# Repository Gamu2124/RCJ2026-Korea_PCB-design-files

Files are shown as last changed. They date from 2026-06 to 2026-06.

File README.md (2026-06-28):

# RCJ2026-Korea_PCB-design-files

This repository contains the PCB design files for RoboCup Junior 2026.

### Overview

This repository provides the PCB design files used in the RoboCup Junior 2026 competition.

The files are available for reference, manufacturing, modification, and educational purposes.

### Contents

The repository may include:

* KiCad project files (`.kicad_pro`)
* Schematic files (`.kicad_sch`)
* PCB layout files (`.kicad_pcb`)
* Manufacturing files (Gerber, Drill, etc., if available)
* Custom footprints and symbol libraries (if required)

### Software

These PCB design files were created using **KiCad**.

For the best compatibility, it is recommended to use the same major version of KiCad that was used to create the project.

### Notes

* These files are provided for reference and educational purposes.
* Manufacturing or modifying the boards is done at your own responsibility.
* Some electronic components may require suitable alternatives depending on availability.

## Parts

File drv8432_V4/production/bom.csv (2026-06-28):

Designator | Footprint | Quantity | Value | LCSC Part #
C1, C4, C5, C6, C7 | 0603 | 5 | 0.1u
C2 | C_Elec_8x10.2 | 1 | 220u
C3 | 1206 | 1 | 1u | C1848
D1 | 0603 | 1 | LED
J1, J2 | PinHeader_1x06_P2.54mm_Vertical | 2 | Conn_01x06_Pin
R1 | 0402 | 1 | 47k
R2 | 0603 | 1 | 1
R3 | 0805 | 1 | 25 | C17594
U1 | HSOP-36-1EP_11.0x15.9mm_P0.65mm_SlugUp | 1 | DRV8432

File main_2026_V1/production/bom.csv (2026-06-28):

Designator | Footprint | Quantity | Value | LCSC Part #
BNO_1, J17, J2, NONE_1 | PinSocket_1x04_P2.54mm_Vertical | 4 | Conn_01x04_Socket
C1, C14, C2, C8, C9 | 1206 | 5 | 10
C12, C16, C18, C22, C23, C24, C25, C26, C27, C28, C29, C30, C31, C32, C33, C34, C35, C36, C37, C38, C39, C40, C41, C42, C43, C44 | 0603 | 26 | 0.1 | C1581
C13, C17, C19, C20 | CP_Elec_6.3x5.4 | 4 | 100
C15 | C_Disc_D5.0mm_W2.5mm_P2.50mm | 1 | 0.1
C21 | 0603 | 1 | 0.1 | C1848
C3 | CP_Radial_D10.0mm_P5.00mm | 1 | 1000
C4, C6 | 1206 | 2 | 10uf
C5, C7 | CP_Elec_6.3x5.4 | 2 | 100uf
CAM_1, CAM_2, CAM_3 | SEEED_110990030 | 3 | Conn_01x04_Socket
D1, D2 | D_A-405_P10.16mm_Horizontal | 2 | D_Schottky
D10, D11, D12, D13, D14, D15, D16, D17, D18, D19, D20, D21, D22, D23, D24, D25, D26, D3, D4, D5, D6, D7, D8, D9 | LED_WS2812B_PLCC4_5.0x5.0mm_P3.2mm | 24 | WS2812B
DPDM_1 | PinSocket_1x02_P2.54mm_Vertical | 1 | Conn_01x02_Socket
J1, KICK_1 | JST_XH_B3B-XH-A_1x03_P2.50mm_Vertical | 2 | Conn_01x03_Socket
J10, J13, J16 | PinHeader_2x02_P2.54mm_Vertical | 3 | Conn_02x02_Counter_Clockwise
J11 | JST_XH_B4B-XH-A_1x04_P2.50mm_Vertical | 1 | USS_1
J12 | JST_XH_B4B-XH-A_1x04_P2.50mm_Vertical | 1 | USS_2
J14 | JST_XH_B4B-XH-A_1x04_P2.50mm_Vertical | 1 | USS_3
J15 | JST_XH_B4B-XH-A_1x04_P2.50mm_Vertical | 1 | USS_4
J3 | PinSocket_1x06_P2.54mm_Vertical | 1 | Conn_01x06_Socket
J4, J5 | PinSocket_1x24_P2.54mm_Vertical | 2 | Conn_01x24_Socket
J6 | USB_C_Receptacle_XKB_U262-16XN-4BVC11 | 1 | TYPE-C_LINE
J8 | USB_C_Receptacle_XKB_U262-16XN-4BVC11 | 1 | TYPE-C_BALL
J9 | USB_C_Receptacle_XKB_U262-16XN-4BVC11 | 1 | TYPE-C_main
LED_1, PHOTO_1 | JST_XH_B2B-XH-AM_1x02_P2.50mm_Vertical | 2 | Conn_01x02_Socket
LINE_1, MOTOR_1 | TE_84952-6_1x06-1MP_P1.0mm_Horizontal | 2 | Conn_01x06_Socket
NEOPIX1 | SOT-23 | 1 | BSS138 | C192057
R1, R2 | R_Axial_DIN0207_L6.3mm_D2.5mm_P10.16mm_Horizontal | 2 | 10k
R10, R11, R4, R5, R8, R9 | 0603 | 6 | 5.1k | C26033
R12 | R_Axial_DIN0207_L6.3mm_D2.5mm_P10.16mm_Horizontal | 1 | 3.3k
R13 | R_Axial_DIN0207_L6.3mm_D2.5mm_P10.16mm_Horizontal | 1 | 3.3k | C22978
R14, R17 | 0603 | 2 | 1k | C22978
R15 | R_Axial_DIN0204_L3.6mm_D1.6mm_P5.08mm_Horizontal | 1 | 50
R16 | 0603 | 1 | 100k | C23098
R18, R19 | 1206 | 2 | 10k | C1489
R3 | R_Axial_DIN0207_L6.3mm_D2.5mm_P10.16mm_Horizontal | 1 | 1k
SW1, SW2, SW3, SW4 | Switch_SKRPABE010 | 4 | SW_Push
TACT_1, TACT_2, TACT_3 | SW_PUSH-12mm | 3 | SW_Push
TOGGLE_1 | PinSocket_1x03_P2.54mm_Vertical | 1 | SW_SPDT
U1 | SOT-223 | 1 | LM1117MP-3.3_module
U2 | DPAK172P1054X200-6N | 1 | BD50FD0W_cpu
U3 | DPAK172P1054X200-6N | 1 | BD50FD0W_cam
U4 | SOT-223 | 1 | LM1117MP-3.3
U6 | XIAO-ESP32-S3-DIP | 1 | XIAO-ESP32-S3-DIP_uss
U7 | XIAO-ESP32-S3-DIP | 1 | XIAO-ESP32-S3-DIP_ui

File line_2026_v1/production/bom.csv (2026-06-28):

Designator | Footprint | Quantity | Value | LCSC Part #
C1, C10, C11, C12, C18, C3, C4, C5, C6, C7, C8, C9 | 0402 | 12 | 0.1
C13 | 0402 | 1 | 4.7 | C1872
C14, C15, C2 | 0402 | 3 | 4.7
C16, C17 | 0402 | 2 | 15p | C1548
C19 | CP_Elec_5x5.4 | 1 | 100
C20 | C_Elec_4x5.4 | 1 | 1u | C3348
D1, D10, D11, D12, D13, D14, D15, D16, D17, D18, D19, D2, D20, D21, D22, D23, D24, D25, D26, D27, D28, D29, D3, D30, D31, D32, D35, D36, D37, D38, D4, D41, D42, D43, D44, D47, D48, D49, D5, D50, D6, D7, D8, D9 | 0603 | 44 | NJL
D33 | 0603 | 1 | BLUE
D34 | 0603 | 1 | GREEN
D53, D54, D55, D56, D57, D58, D59, D60, D61, D62, D63, D64 | D_SOD-323 | 12 | SBD
J1 | JST_XH_S2B-XH-A_1x02_P2.50mm_Horizontal | 1 | Conn_01x02_Socket
L1 | Inductor_0806_2016 | 1 | 3.3 | C42411119
LED_1, LED_10, LED_11, LED_12, LED_13, LED_14, LED_15, LED_16, LED_17, LED_18, LED_19, LED_2, LED_20, LED_21, LED_22, LED_23, LED_24, LED_25, LED_26, LED_27, LED_28, LED_29, LED_3, LED_30, LED_31, LED_32, LED_33, LED_34, LED_35, LED_36, LED_39, LED_4, LED_40, LED_41, LED_42, LED_45, LED_46, LED_47, LED_48, LED_5, LED_6, LED_7, LED_8, LED_9 | 0603 | 44 | LED
LINE1 | USB_C_Receptacle_XKB_U262-16XN-4BVC11 | 1 | TYPE-C_LINE
LINE_1 | TE_84952-6_1x06-1MP_P1.0mm_Horizontal | 1 | Conn_01x06_Socket
Q1 | SOT-23 | 1 | AO3400A
R1, R10, R100, R101, R104, R105, R106, R107, R11, R12, R13, R14, R15, R16, R17, R18, R19, R2, R20, R21, R22, R23, R24, R25, R26, R27, R28, R29, R3, R30, R31, R32, R4, R5, R6, R7, R8, R9, R92, R93, R94, R95, R98, R99 | 0603 | 44 | 69.8k | C23098
R110, R111, R112, R113, R114, R115, R116, R117, R118, R119, R120, R121, R33, R34, R35, R36, R37, R38, R39, R40, R41, R42, R43, R44, R45, R46, R47, R48, R49, R50, R51, R52, R53, R54, R55, R56, R57, R58, R59, R60, R61, R62, R63, R64 | 0603 | 44 | 1k | C23098
R128, R129, R131, R132, R134, R135, R71, R72, R73, R74, R75, R76, R77, R78, R79, R80, R81, R82, R83, R84, R85, R86 | 0603 | 22 | 25
R65 | 0603 | 1 | 33 | C177281
R66 | 0402 | 1 | 22 | C174144
R67 | 0402 | 1 | 22
R68 | 0402 | 1 | 1k | C174178
R69 | 0402 | 1 | 15 | C22369173
R70 | 0402 | 1 | 30 | C22356186
R87 | 0805 | 1 | 220
R88 | 0603 | 1 | 10k
R89 | 0603 | 1 | 10k | C23098
R90, R91 | 0603 | 2 | 5.1k | C26033
U1, U10, U11, U12, U13, U14, U15, U16, U17, U18, U19, U2, U20, U21, U22, U3, U4, U5, U6, U7, U8, U9 | SOIC-8_3.9x4.9mm_P1.27mm | 22 | LM393
U25 | RP2350B_QFN-80_EP_10.573x10.573_Pitch0.4mm | 1 | RP2350B-QFN80
U26 | SOIC-8_5.23x5.23mm_P1.27mm | 1 | W25Q128JVS
Y1 | Crystal_SMD_3225-4Pin_3.2x2.5mm | 1 | Crystal_GND24 | C20625731

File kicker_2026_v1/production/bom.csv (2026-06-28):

Designator | Footprint | Quantity | Value | LCSC Part #
D1 | D_SOD-323_HandSoldering | 1 | SBD
D2 | D_SOD-123F | 1 | D
D4 | D_A-405_P10.16mm_Horizontal | 1 | D
J1, SOLE1 | JST_XH_S2B-XH-A_1x02_P2.50mm_Horizontal | 2 | Conn_01x02_Socket
J10, J11, J7, J8 | PinSocket_1x01_P2.54mm_Vertical | 4 | Conn_01x01_Socket
J2, J3 | PinSocket_1x02_P2.54mm_Vertical | 2 | Conn_01x02_Socket
K1 | SMDIP-8_W7.62mm | 1 | AQW212EHA
LED_D1 | 0603 | 1 | LED
MAIN_1 | JST_XH_S3B-XH-A_1x03_P2.50mm_Horizontal | 1 | Conn_01x03_Socket
Q1 | TO-252-2 | 1 | PMOS
Q2 | TO-220-3_Horizontal_TabDown | 1 | NMOS
R1 | 1206 | 1 | 1.6k | C4908
R10 | 1206 | 1 | 68
R11 | 1206 | 1 | 10k
R2 | 1206 | 1 | 1.6k | C102100
R4 | 2512 | 1 | 1k | C31884
R5 | 2512 | 1 | 3.3k | C1469
R6 | 2512 | 1 | 150 | C25471
R9 | 2512 | 1 | 3k | C2934109

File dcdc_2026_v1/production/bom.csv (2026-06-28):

Designator | Footprint | Quantity | Value | LCSC Part #
C1, C7 | Capacitor_0402_1005 | 2 | 0.1
C10, C11, C3, C4, C9 | CP_Elec_5x5.4 | 5 | 22
C12 | CP_Elec_4x5.4 | 1 | 10
C13 | CP_Elec_5x5.7 | 1 | 2.7 | C487141
C2 | CP_Elec_5x5.4 | 1 | 22 | C2887274
C5 | CP_Elec_4x5.4 | 1 | 10 | C2992602
C6 | CP_Elec_5x5.7 | 1 | 2.7
C8 | 0603 | 1 | 0.1
D1 | D_SOD-123F | 1 | D
F1 | Fuseholder_Clip-5x20mm_Keystone_3517_Inline_P23.11x6.76mm_D1.70mm_Horizontal | 1 | Fuse
J1 | PinSocket_1x02_P2.54mm_Vertical | 1 | oled
J2 | AMASS_XT30U-M_1x02_P5.0mm_Vertical | 1 | md
J3 | JST_XH_S3B-XH-A_1x03_P2.50mm_Horizontal | 1 | Conn_01x03_Socket
J4 | JST_XH_S2B-XH-A_1x02_P2.50mm_Horizontal | 1 | md_logic
J5 | JST_XH_S2B-XH-A_1x02_P2.50mm_Horizontal | 1 | line
J6 | JST_XH_S2B-XH-A_1x02_P2.50mm_Horizontal | 1 | kick
L1 | L_Bourns_SRP7028A_7.3x6.6mm | 1 | 3.3
L2 | IND_ETQP5M4R7YFM | 1 | 4.7
LIPO_1 | AMASS_XT30U-M_1x02_P5.0mm_Vertical | 1 | XT30_IN
Q1 | TO-252-2 | 1 | PMOS
R1 | R_Axial_DIN0207_L6.3mm_D2.5mm_P10.16mm_Horizontal | 1 | 10k
R10 | 0805 | 1 | 200k
R11 | 0805 | 1 | 22.1k | C17552
R2 | 0805 | 1 | 69.8k | C17803
R3 | 0402 | 1 | 10.5k | C25850
R4 | 0805 | 1 | 200k | C17539
R5 | 0805 | 1 | 22.1k
R6 | R_Axial_DIN0207_L6.3mm_D2.5mm_P10.16mm_Horizontal | 1 | 10k | C26033
R7 | 0603 | 1 | 150k | C177617
R8 | R_Axial_DIN0207_L6.3mm_D2.5mm_P10.16mm_Horizontal | 1 | 3.3k | C26033
R9 | 0805 | 1 | 22k
RV1 | Potentiometer_Bourns_3314J_Vertical | 1 | 50k
SW | Rocker_SW | 1 | rocker_SW
SW1 | PinSocket_1x02_P2.54mm_Vertical | 1 | SW_SPST
U1 | SO-8EP_DIO | 1 | AP64500SP-3.3v
U2 | SO-8EP_DIO | 1 | AP64500SP-7v

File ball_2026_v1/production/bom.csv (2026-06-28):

Designator | Footprint | Quantity | Value | LCSC Part #
A1, A10, A11, A12, A13, A14, A15, A16, A17, A18, A19, A2, A20, A21, A22, A23, A24, A3, A4, A5, A6, A7, A8, A9 | XDCR_TSSP4038 | 24 | TSSP4038
C1, C16, C4 | 0402 | 3 | 4.7
C10, C13 | 0402 | 2 | 15p | C1548
C11, C12, C14, C15, C2, C5, C6, C7, C8, C9 | 0402 | 10 | 0.1
C17 | CP_Elec_6.3x5.7 | 1 | 150 | C249851
C3 | 0402 | 1 | 4.7 | C1872
D1 | 0603 | 1 | BLUE
D2 | 0603 | 1 | GREEN
J1, J2, J3 | PinHeader_2x02_P2.54mm_Vertical | 3 | Conn_02x02_Counter_Clockwise
L1 | Inductor_0806_2016 | 1 | 3.3 | C42411119
R1 | 0402 | 1 | 15 | C22369173
R2 | 0402 | 1 | 30 | C22356186
R3 | 0402 | 1 | 1k | C174178
R4 | 0603 | 1 | 33 | C177281
R6 | 0402 | 1 | 22 | C174144
R7 | 0402 | 1 | 22
U1 | SOIC-8_5.23x5.23mm_P1.27mm | 1 | W25Q128JVS
U2 | Package_QFN-60-1EP_7x7mm_P0.4mm_EP3.4x3.4mm_hand | 1 | RP2350_60QFN
Y1 | Crystal_SMD_3225-4Pin_3.2x2.5mm | 1 | Crystal_GND24 | C20625731

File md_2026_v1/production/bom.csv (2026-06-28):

Designator | Footprint | Quantity | Value | LCSC Part #
J1 | TE_84952-6_1x06-1MP_P1.0mm_Horizontal | 1 | Conn_01x06_Socket
J1001 | JST_XH_B2B-XH-A_1x02_P2.50mm_Vertical | 1 | Conn_01x02_Socket
J1002, J2 | AMASS_XT30U-M_1x02_P5.0mm_Vertical | 2 | md
J12, J13, J14, J15 | PinSocket_1x06_P2.54mm_Vertical | 4 | Conn_01x06_Socket
J3, J4, J5, J6 | JST_XH_S2B-XH-A_1x02_P2.50mm_Horizontal | 4 | Conn_01x02_Socket
J7 | JST_XH_B2B-XH-A_1x02_P2.50mm_Vertical | 1 | md_logic
R1 | R_Axial_DIN0207_L6.3mm_D2.5mm_P10.16mm_Horizontal | 1 | 10k | C15401

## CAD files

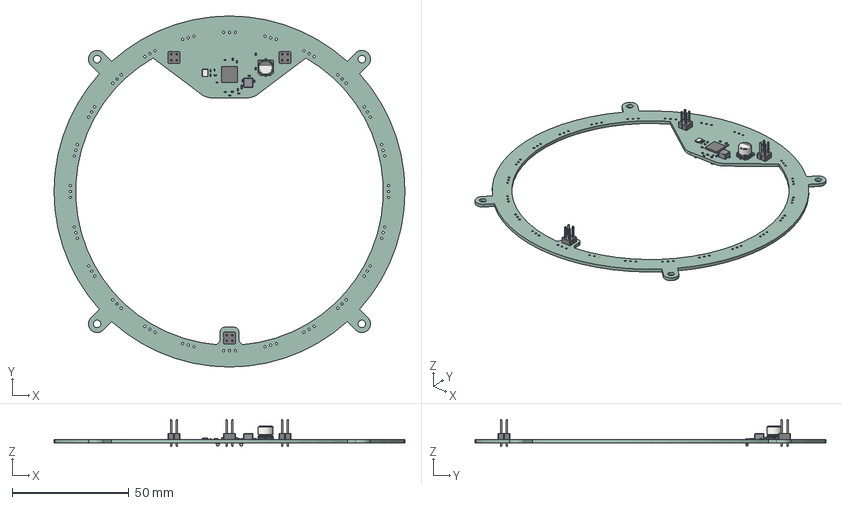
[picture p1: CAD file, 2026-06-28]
ball_2026_v1/ball_2026_v1.step
150.0 x 150.0 x 11.5 mm
C_0402_1005Metric x 16
R_0603_1608Metric
Crystal_SMD_3225-4Pin_3.2x2.5mm
R_0402_1005Metric x 5
QFN-56-1EP_7x7mm_P0.4mm_EP5.6x5.6mm
PinHeader_2x02_P2.54mm_Vertical x 3
L_Abracon_ASPI-0425
CP_Elec_6.3x5.7
LED_0603_1608Metric x 2
ball_2026_v1_PCB

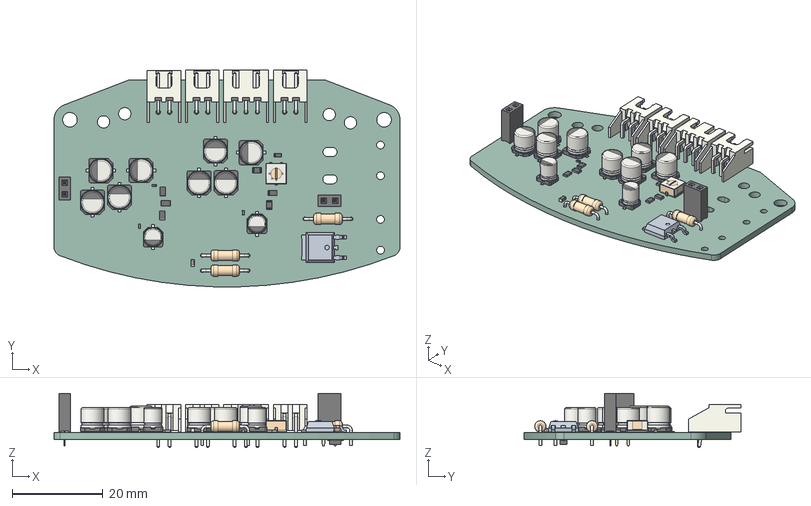
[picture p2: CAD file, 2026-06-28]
dcdc_2026_v1/dcdc_2026_v1.step
76.1 x 47.6 x 11.9 mm
CP_Elec_5x5.4 x 6
C_0402_1005Metric x 2
CP_Elec_4x5.4 x 2
R_0805_2012Metric x 6
PinSocket_1x02_P2.54mm_Vertical x 2
JST_XH_S2B-XH-A_1x02_P2.50mm_Horizontal x 3
R_Axial_DIN0207_L6.3mm_D2.5mm_P10.16mm_Horizontal x 3
Potentiometer_Bourns_3314J_Vertical
C_0603_1608Metric
dcdc_2026_v1 1.22.1
R_0603_1608Metric
CP_Elec_5x5.7 x 2
R_0402_1005Metric
JST_XH_S3B-XH-A_1x03_P2.50mm_Horizontal
D_SOD-123F
dcdc_2026_v1_PCB

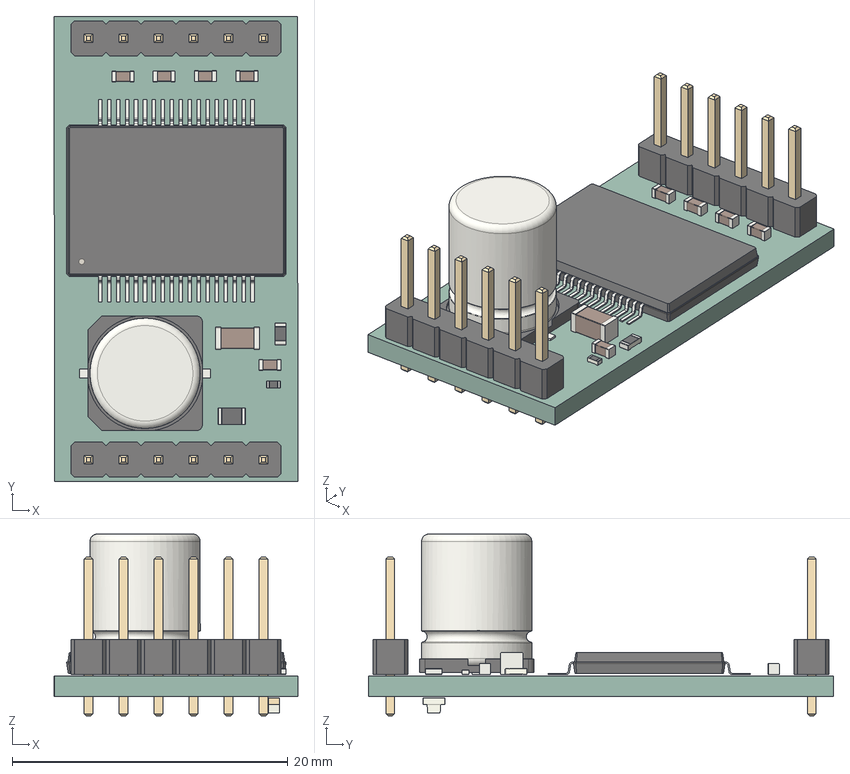
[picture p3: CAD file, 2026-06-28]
drv8432_V4/drv8432_V3.step
17.7 x 33.7 x 13.2 mm
R_0603_1608Metric
R_0402_1005Metric
C_0603_1608Metric x 5
PinHeader_1x06_P2.54mm_Vertical x 2
C_Elec_8x10.2
R_0805_2012Metric
HSOP-36-1EP_11.0x15.9mm_P0.65mm_SlugUp
C_1206_3216Metric
LED_0603_1608Metric
drv8432_V3_PCB

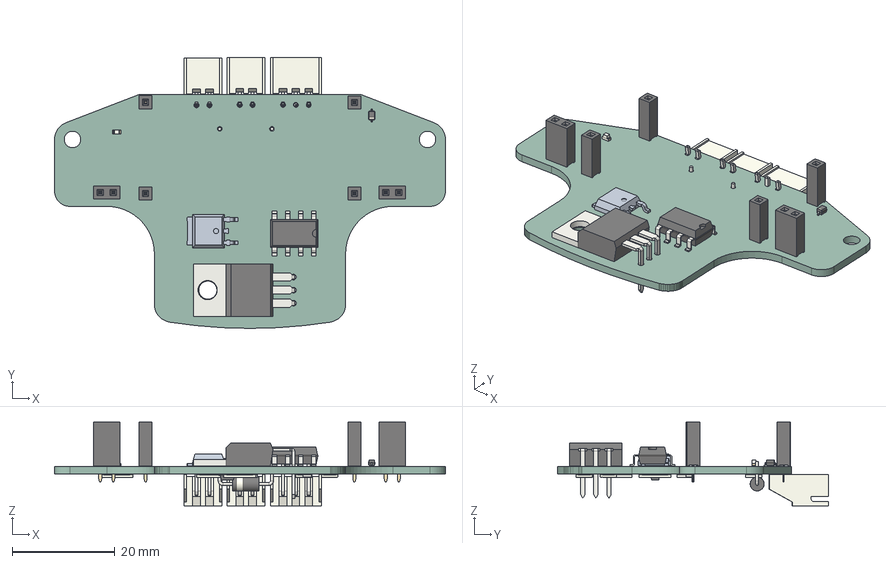
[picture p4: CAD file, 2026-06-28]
kicker_2026_v1/kick_.step
76.1 x 52.7 x 16.3 mm
PinSocket_1x01_P2.54mm_Vertical x 4
SMDIP-8_W7.62mm
PinSocket_1x02_P2.54mm_Vertical x 2
kick_ 1.7.1
D_SOD-323
TO-220-3_Horizontal_TabDown
LED_0603_1608Metric
R_1206_3216Metric x 4
R_2512_6332Metric x 4
D_A-405_P10.16mm_Horizontal
D_SOD-123F
JST_XH_S2B-XH-A_1x02_P2.50mm_Horizontal x 2
JST_XH_S3B-XH-A_1x03_P2.50mm_Horizontal
kick__PCB

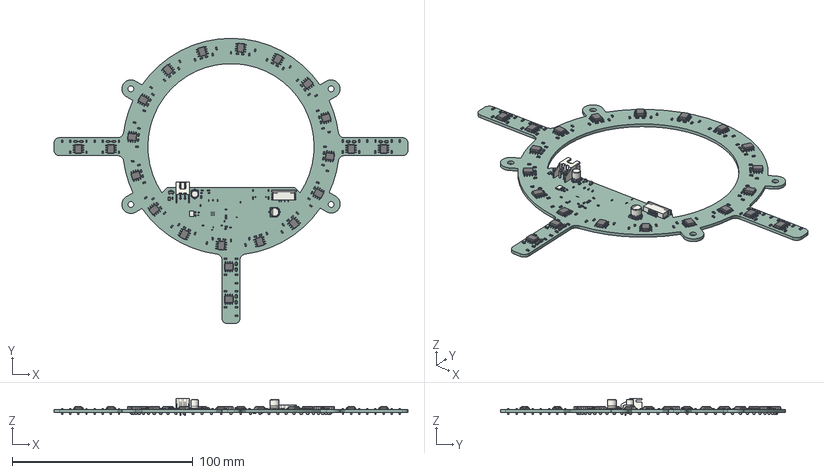
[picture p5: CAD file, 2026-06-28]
line_2026_v1/line_2026_v1.step
196.0 x 158.0 x 9.50 mm
R_0603_1608Metric x 115
R_0402_1005Metric x 5
SOIC-8_3.9x4.9mm_P1.27mm x 22
C_0402_1005Metric x 18
D_SOD-323 x 12
JST_XH_S2B-XH-A_1x02_P2.50mm_Horizontal
C_Elec_4x5.4
LED_0603_1608Metric x 90
CP_Elec_5x5.4
Crystal_SMD_3225-4Pin_3.2x2.5mm
R_0805_2012Metric
SOT-23
TE_84952-6_1x06-1MP_P1.0mm_Horizontal
line_2026_v1_PCB

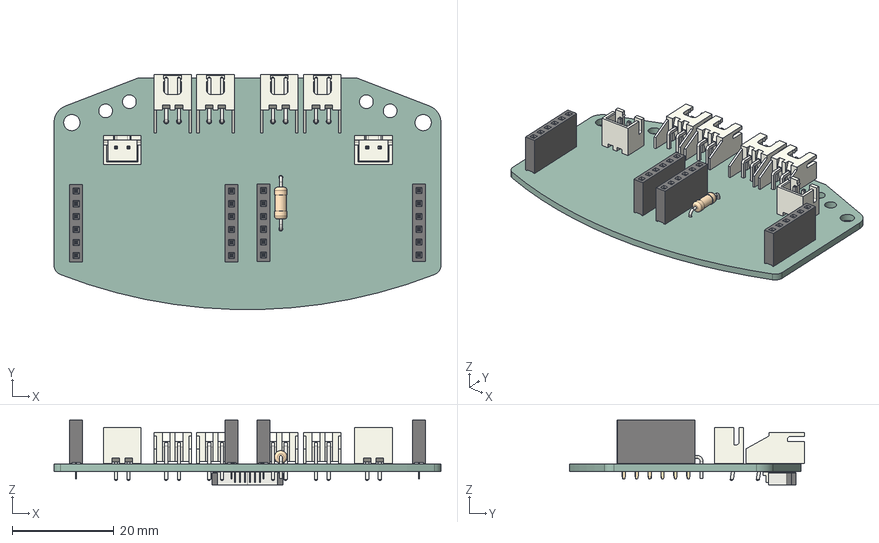
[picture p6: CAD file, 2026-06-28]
md_2026_v1/md_2026_v1.step
76.1 x 46.2 x 12.7 mm
JST_XH_S2B-XH-A_1x02_P2.50mm_Horizontal x 4
R_Axial_DIN0207_L6.3mm_D2.5mm_P10.16mm_Horizontal
JST_XH_B2B-XH-A_1x02_P2.50mm_Vertical x 2
PinSocket_1x06_P2.54mm_Vertical x 4
TE_84952-6_1x06-1MP_P1.0mm_Horizontal
md_2026_v1_PCB

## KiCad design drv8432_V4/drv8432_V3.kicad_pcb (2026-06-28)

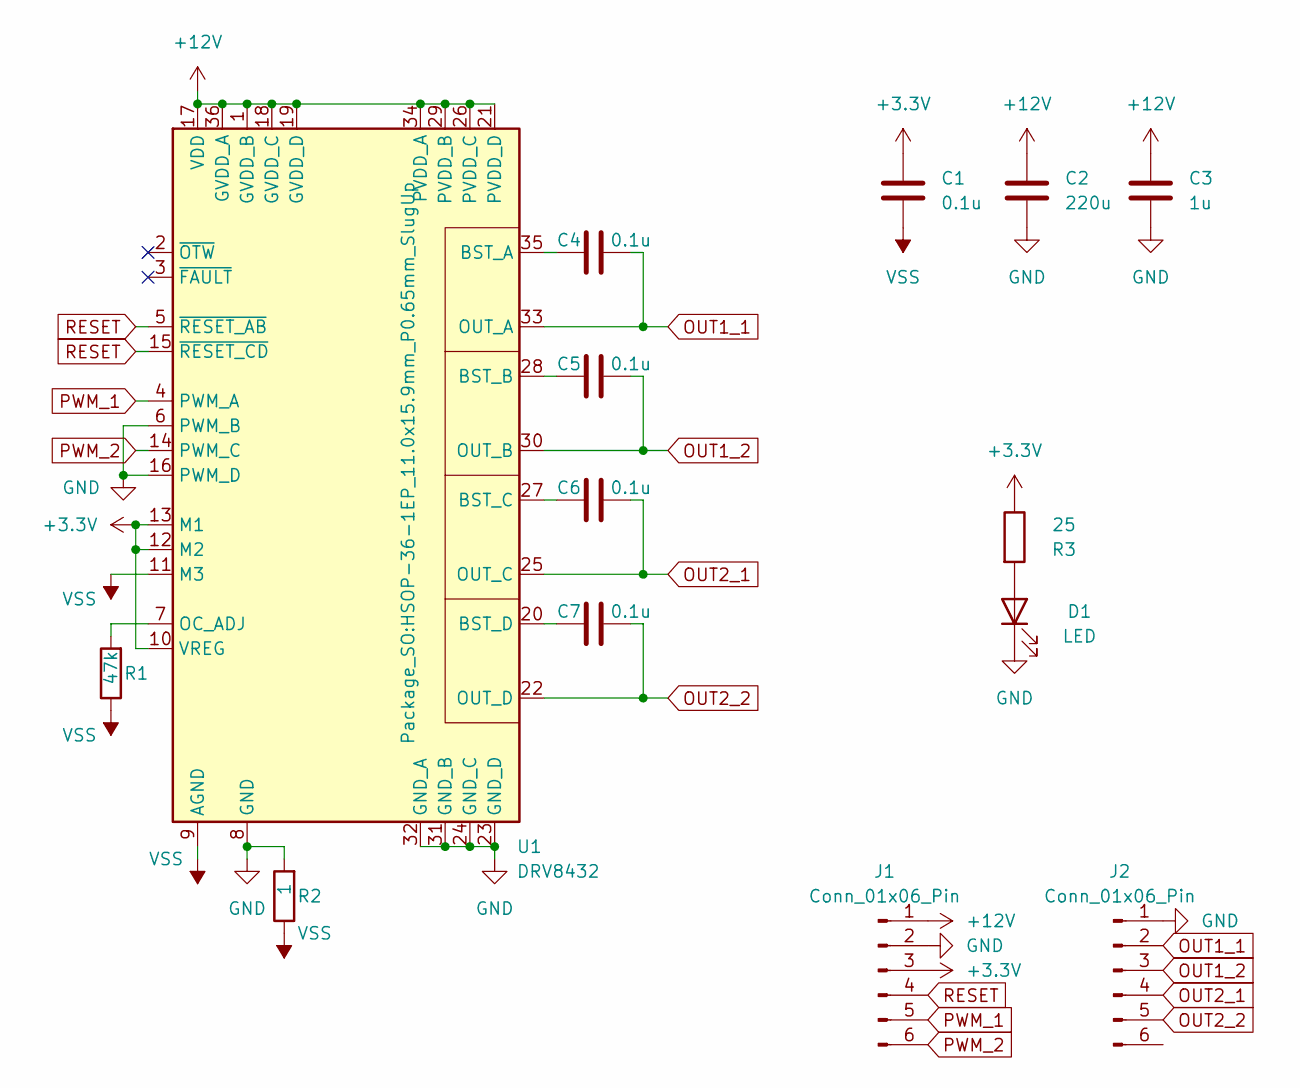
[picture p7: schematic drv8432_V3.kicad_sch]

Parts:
C1, C4, C5, C6, C7: 0.1u; C_0603_1608Metric
C2: 220u; C_Elec_8x10.2
C3: 1u; C_1206_3216Metric; LCSC C1848
D1: LED; LED_0603_1608Metric_Pad1.05x0.95mm_HandSolder
J1, J2: Conn_01x06_Pin; PinHeader_1x06_P2.54mm_Vertical
R1: 47k; R_0402_1005Metric
R2: 1; R_0603_1608Metric
R3: 25; R_0805_2012Metric; LCSC C17594
U1: DRV8432; HSOP-36-1EP_11.0x15.9mm_P0.65mm_SlugUp

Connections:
+3.3V: C1.1, J1.3, R3.1, U1.10 (VREG), U1.12 (M2), U1.13 (M1)
+12V: C2.1, C3.1, J1.1, U1.1 (GVDD_B), U1.17 (VDD), U1.18 (GVDD_C), U1.19 (GVDD_D), U1.21 (PVDD_D), U1.26 (PVDD_C), U1.29 (PVDD_B), U1.34 (PVDD_A), U1.36 (GVDD_A)
GND: C2.2, C3.2, D1.1 (K), J1.2, J2.1, R2.2, U1.6 (PWM_B), U1.8 (GND), U1.16 (PWM_D), U1.23 (GND_D), U1.24 (GND_C), U1.31 (GND_B), U1.32 (GND_A)
unnamed: D1.2 (A), R3.2
unnamed: C4.1, U1.35 (BST_A)
unnamed: C5.1, U1.28 (BST_B)
unnamed: C6.1, U1.27 (BST_C)
unnamed: C7.1, U1.20 (BST_D)
unnamed: R1.2, U1.7 (OC_ADJ)
OUT1_1: C4.2, J2.2, U1.33 (OUT_A)
OUT1_2: C5.2, J2.3, U1.30 (OUT_B)
OUT2_1: C6.2, J2.4, U1.25 (OUT_C)
OUT2_2: C7.2, J2.5, U1.22 (OUT_D)
PWM_1: J1.5, U1.4 (PWM_A)
PWM_2: J1.6, U1.14 (PWM_C)
RESET: J1.4, U1.5 (~RESET_AB), U1.15 (~RESET_CD)
VSS: C1.2, R1.1, R2.1, U1.9 (AGND), U1.11 (M3)

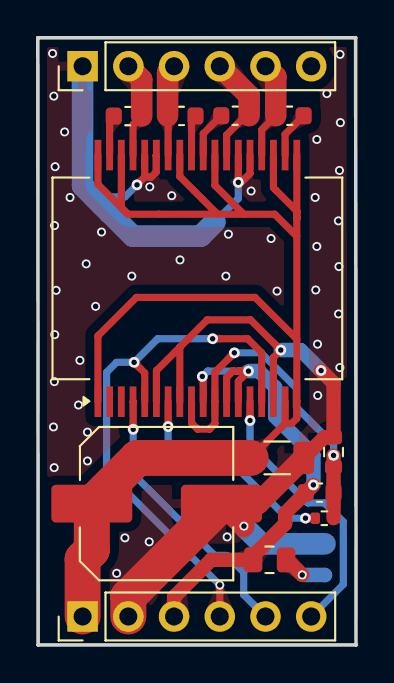
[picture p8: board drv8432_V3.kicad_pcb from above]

Board: 2 copper layers, 17.7 x 33.7 mm, 14 parts (1 on the bottom side), 17 nets.

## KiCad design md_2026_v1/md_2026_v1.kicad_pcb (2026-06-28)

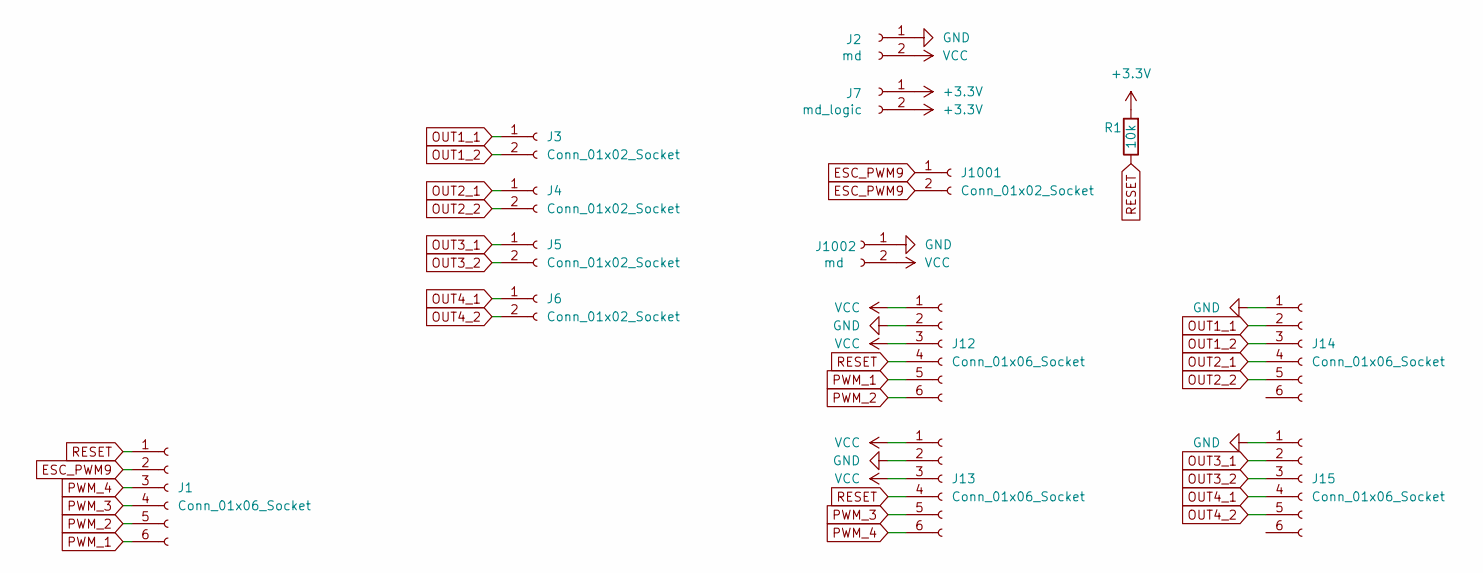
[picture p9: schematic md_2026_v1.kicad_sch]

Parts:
J1: Conn_01x06_Socket; TE_84952-6_1x06-1MP_P1.0mm_Horizontal
J2, J1002: md; AMASS_XT30U-M_1x02_P5.0mm_Vertical
J3, J4, J5, J6: Conn_01x02_Socket; JST_XH_S2B-XH-A_1x02_P2.50mm_Horizontal
J7: md_logic; JST_XH_B2B-XH-A_1x02_P2.50mm_Vertical
J12, J13, J14, J15: Conn_01x06_Socket; PinSocket_1x06_P2.54mm_Vertical
J1001: Conn_01x02_Socket; JST_XH_B2B-XH-A_1x02_P2.50mm_Vertical
R1: 10k; R_Axial_DIN0207_L6.3mm_D2.5mm_P10.16mm_Horizontal; LCSC C15401

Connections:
+3.3V: J7.1, J7.2, R1.2
ESC_PWM9: J1.2, J1001.1, J1001.2
GND: J2.1, J12.2, J13.2, J14.1, J15.1, J1002.1
OUT1_1: J3.1, J14.2
OUT1_2: J3.2, J14.3
OUT2_1: J4.1, J14.4
OUT2_2: J4.2, J14.5
OUT3_1: J5.1, J15.2
OUT3_2: J5.2, J15.3
OUT4_1: J6.1, J15.4
OUT4_2: J6.2, J15.5
PWM_1: J1.6, J12.5
PWM_2: J1.5, J12.6
PWM_3: J1.4, J13.5
PWM_4: J1.3, J13.6
RESET: J1.1, J12.4, J13.4, R1.1
VCC: J2.2, J12.1, J12.3, J13.1, J13.3, J1002.2

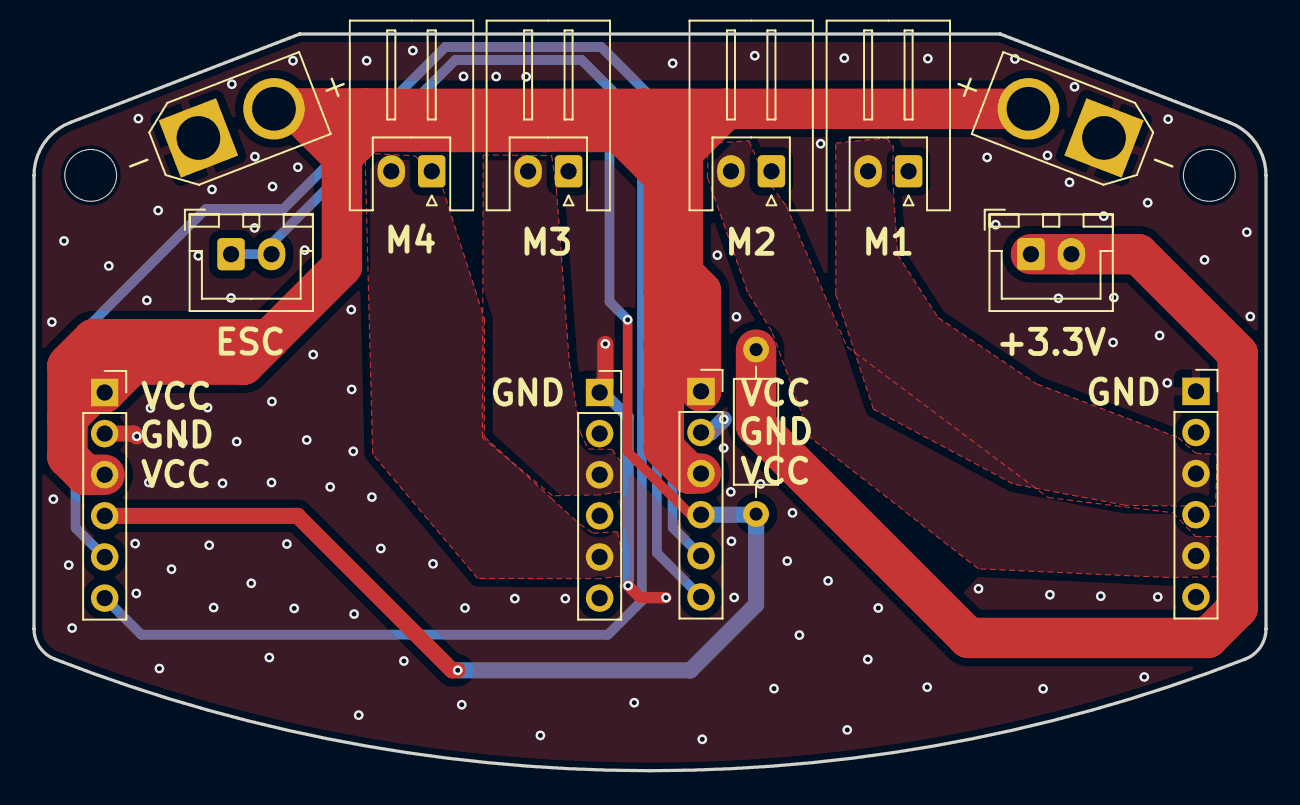
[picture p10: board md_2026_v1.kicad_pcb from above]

Board: 2 copper layers, 76.1 x 45.5 mm, 16 parts (1 on the bottom side), 17 nets.

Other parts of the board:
H1, H1#2: MountingHole; MountingHole_3.2mm_M3

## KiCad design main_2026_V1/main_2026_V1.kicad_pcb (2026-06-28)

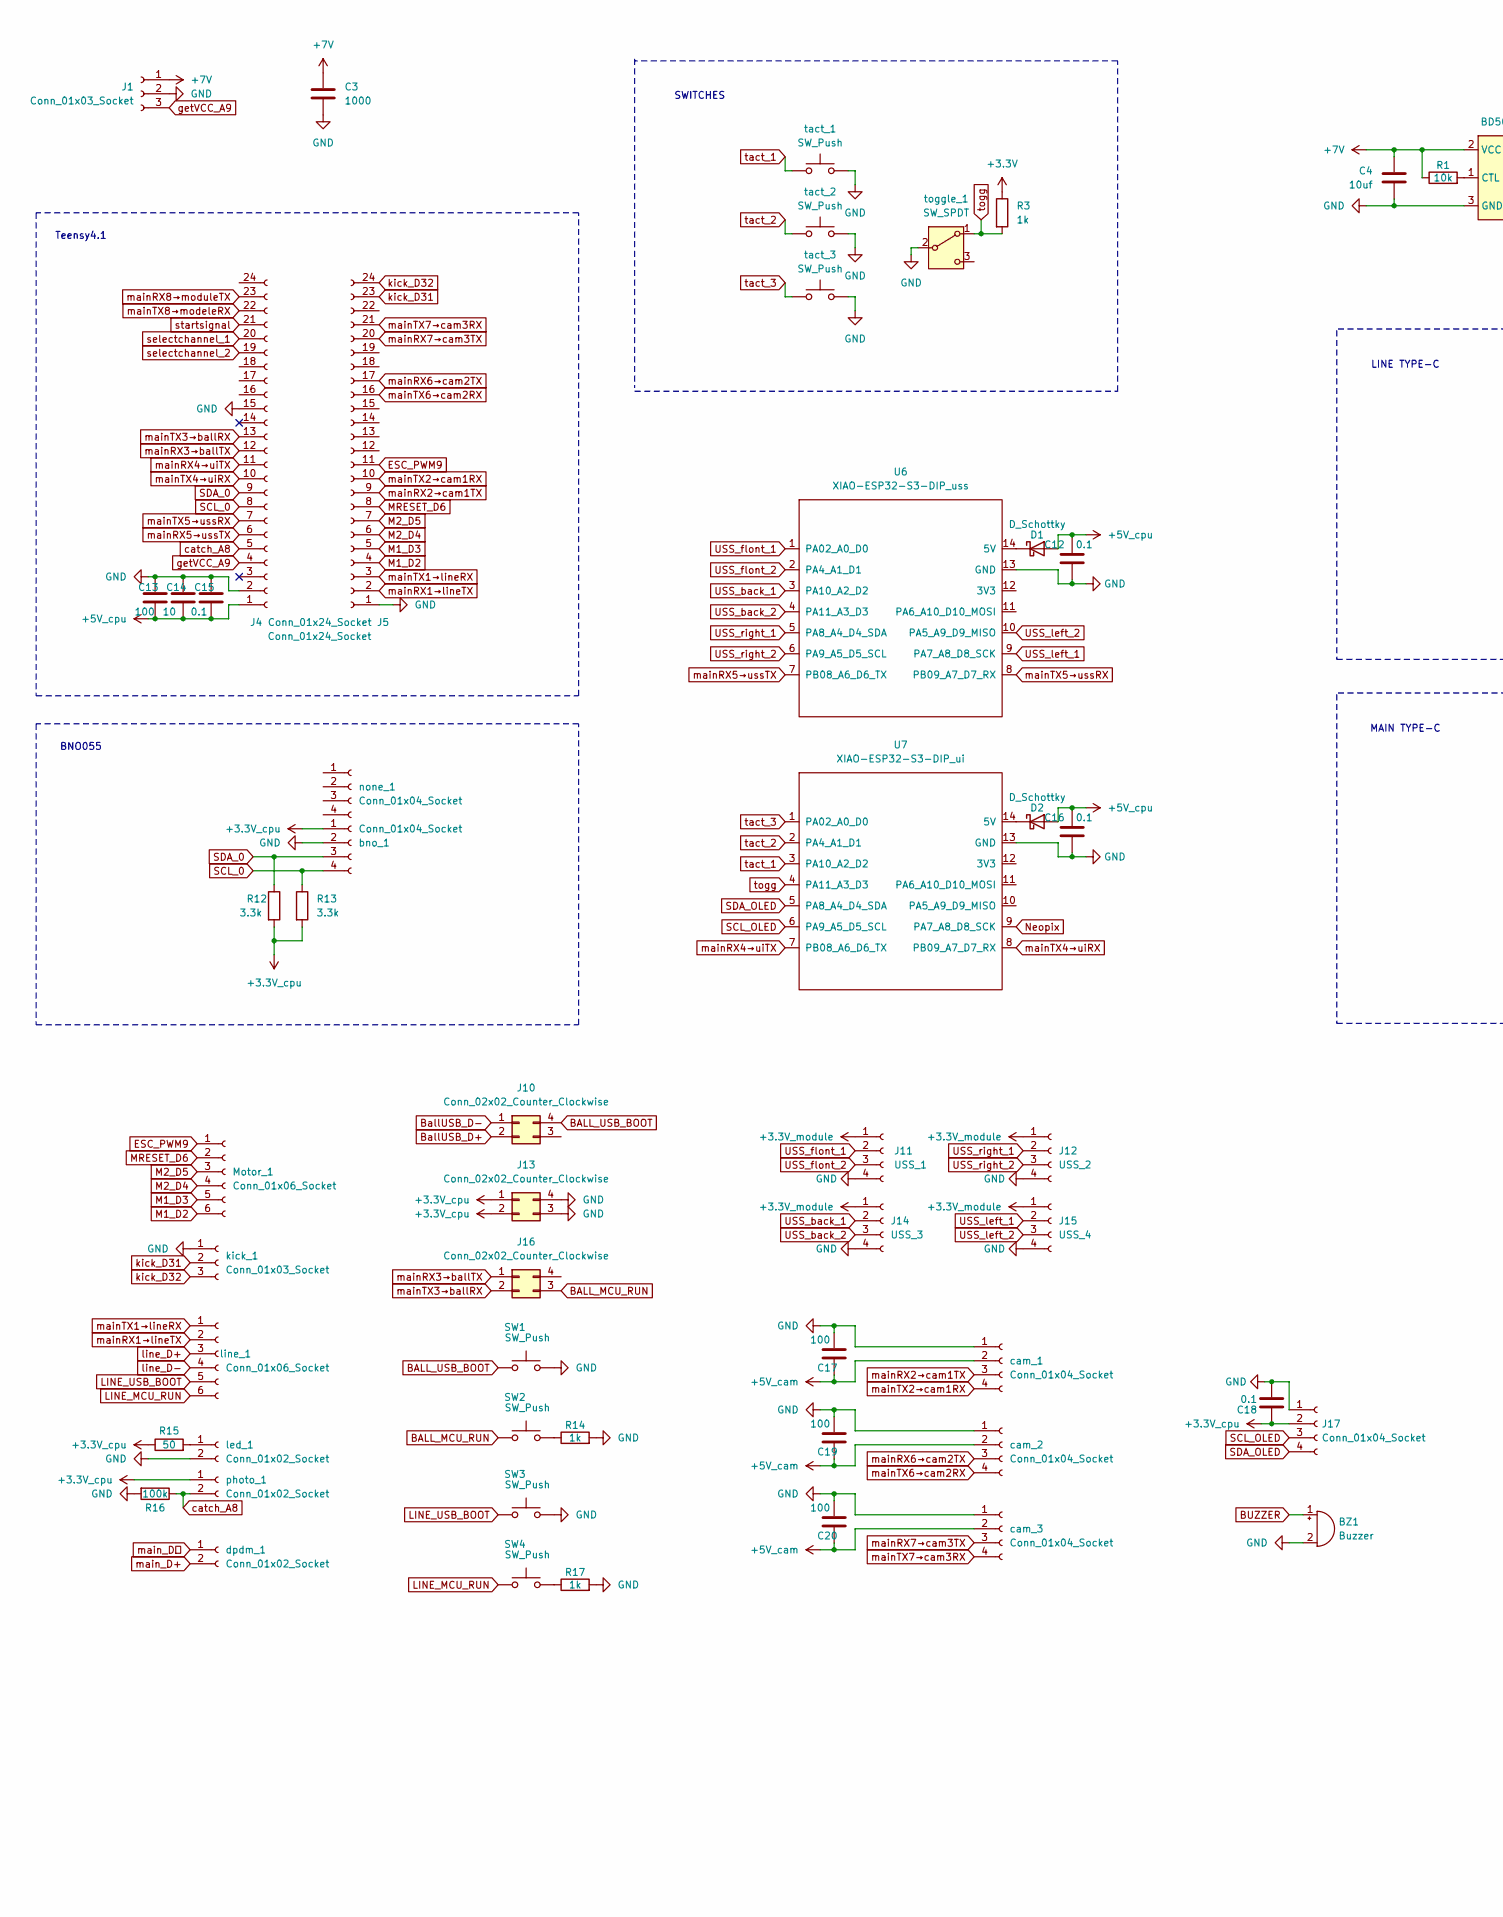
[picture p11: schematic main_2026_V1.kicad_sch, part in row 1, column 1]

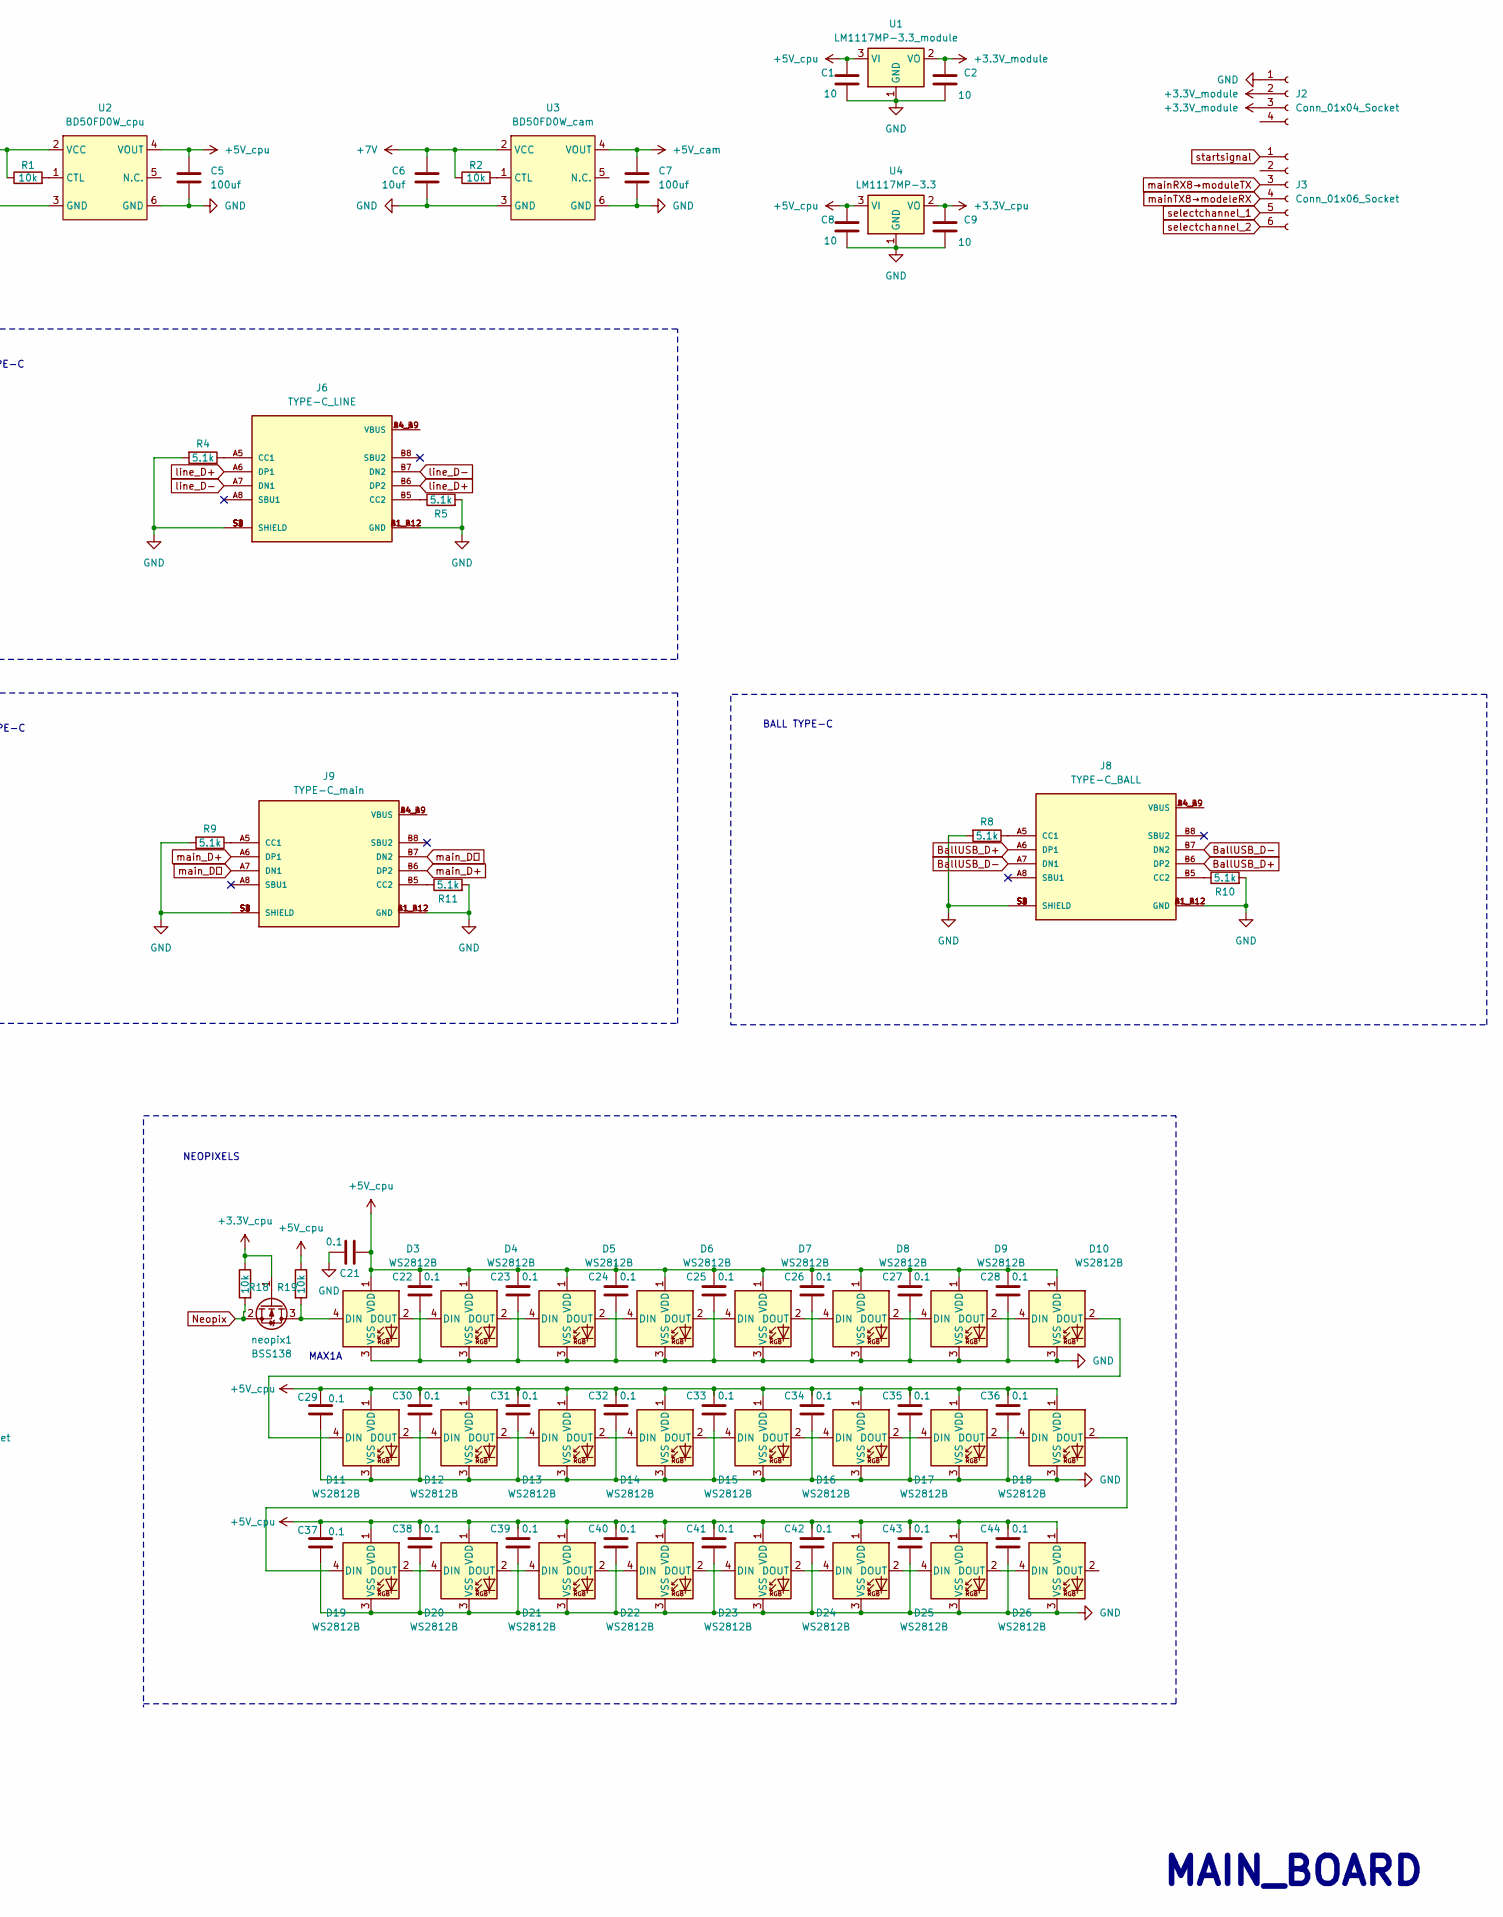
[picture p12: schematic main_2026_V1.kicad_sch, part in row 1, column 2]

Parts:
BZ1: Buzzer; XDCR_KXG0909P
C1, C2, C8, C9, C14: 10; C_1206_3216Metric_Pad1.33x1.80mm_HandSolder
C3: 1000; CP_Radial_D10.0mm_P5.00mm
C4, C6: 10uf; C_1206_3216Metric_Pad1.33x1.80mm_HandSolder
C5, C7: 100uf; CP_Elec_6.3x5.4
C12, C16, C18, C22, C23, C24, C25, C26, C27, C28, C29, C30, C31, C32, C33, C34, C35, C36, C37, C38, C39, C40, C41, C42, C43, C44: 0.1; C_0603_1608Metric_Pad1.08x0.95mm_HandSolder; LCSC C1581
C13, C17, C19, C20: 100; CP_Elec_6.3x5.4
C15: 0.1; C_Disc_D5.0mm_W2.5mm_P2.50mm
C21: 0.1; C_0603_1608Metric_Pad1.08x0.95mm_HandSolder; LCSC C1848
D1, D2: D_Schottky; D_A-405_P10.16mm_Horizontal
D3, D4, D5, D6, D7, D8, D9, D10, D11, D12, D13, D14, D15, D16, D17, D18, D19, D20, D21, D22, D23, D24, D25, D26: WS2812B; LED_WS2812B_PLCC4_5.0x5.0mm_P3.2mm
J1: Conn_01x03_Socket; JST_XH_B3B-XH-A_1x03_P2.50mm_Vertical
J2, J17: Conn_01x04_Socket; PinSocket_1x04_P2.54mm_Vertical
J3: Conn_01x06_Socket; PinSocket_1x06_P2.54mm_Vertical
J4, J5: Conn_01x24_Socket; PinSocket_1x24_P2.54mm_Vertical
J6: TYPE-C_LINE; USB_C_Receptacle_XKB_U262-16XN-4BVC11; PARTREV B
J8: TYPE-C_BALL; USB_C_Receptacle_XKB_U262-16XN-4BVC11; PARTREV B
J9: TYPE-C_main; USB_C_Receptacle_XKB_U262-16XN-4BVC11; PARTREV B
J10, J13, J16: Conn_02x02_Counter_Clockwise; PinHeader_2x02_P2.54mm_Vertical
J11: USS_1; JST_XH_B4B-XH-A_1x04_P2.50mm_Vertical
J12: USS_2; JST_XH_B4B-XH-A_1x04_P2.50mm_Vertical
J14: USS_3; JST_XH_B4B-XH-A_1x04_P2.50mm_Vertical
J15: USS_4; JST_XH_B4B-XH-A_1x04_P2.50mm_Vertical
Motor_1: Conn_01x06_Socket; TE_84952-6_1x06-1MP_P1.0mm_Horizontal
R1, R2: 10k; R_Axial_DIN0207_L6.3mm_D2.5mm_P10.16mm_Horizontal
R3: 1k; R_Axial_DIN0207_L6.3mm_D2.5mm_P10.16mm_Horizontal
R4, R5, R8, R9, R10, R11: 5.1k; R_0603_1608Metric_Pad0.98x0.95mm_HandSolder; LCSC C26033
R12: 3.3k; R_Axial_DIN0207_L6.3mm_D2.5mm_P10.16mm_Horizontal
R13: 3.3k; R_Axial_DIN0207_L6.3mm_D2.5mm_P10.16mm_Horizontal; LCSC C22978
R14, R17: 1k; R_0603_1608Metric_Pad0.98x0.95mm_HandSolder; LCSC C22978
R15: 50; R_Axial_DIN0204_L3.6mm_D1.6mm_P5.08mm_Horizontal
R16: 100k; R_0603_1608Metric; LCSC C23098
R18, R19: 10k; R_1206_3216Metric; LCSC C1489
SW1, SW2, SW3, SW4: SW_Push; Switch_SKRPABE010
U1: LM1117MP-3.3_module; SOT-223
U2: BD50FD0W_cpu; DPAK172P1054X200-6N
U3: BD50FD0W_cam; DPAK172P1054X200-6N
U4: LM1117MP-3.3; SOT-223
U6: XIAO-ESP32-S3-DIP_uss; XIAO-ESP32-S3-DIP
U7: XIAO-ESP32-S3-DIP_ui; XIAO-ESP32-S3-DIP
bno_1: Conn_01x04_Socket; PinSocket_1x04_P2.54mm_Vertical
cam_1, cam_2, cam_3: Conn_01x04_Socket; SEEED_110990030
dpdm_1: Conn_01x02_Socket; PinSocket_1x02_P2.54mm_Vertical
kick_1: Conn_01x03_Socket; JST_XH_B3B-XH-A_1x03_P2.50mm_Vertical
led_1: Conn_01x02_Socket; JST_XH_B2B-XH-AM_1x02_P2.50mm_Vertical
line_1: Conn_01x06_Socket; TE_84952-6_1x06-1MP_P1.0mm_Horizontal
neopix1: BSS138; SOT-23; LCSC C192057
none_1: Conn_01x04_Socket; PinSocket_1x04_P2.54mm_Vertical
photo_1: Conn_01x02_Socket; JST_XH_B2B-XH-AM_1x02_P2.50mm_Vertical
tact_1, tact_2, tact_3: SW_Push; SW_PUSH-12mm
toggle_1: SW_SPDT; PinSocket_1x03_P2.54mm_Vertical

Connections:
+3.3V: R3.1
+3.3V_cpu: C9.1, C18.1, J13.1, J13.2, J17.2, R12.2, R13.2, R15.1, R18.1, U4.2 (VO), bno_1.1, neopix1.1 (G), photo_1.1
+3.3V_module: C2.1, J2.2, J2.3, J11.1, J12.1, J14.1, J15.1, U1.2 (VO)
+5V_cam: C7.1, C17.1, C19.1, C20.1, U3.4 (VOUT), cam_1.2, cam_2.2, cam_3.2
+5V_cpu: C1.1, C5.1, C8.1, C12.2, C13.2, C14.2, C15.2, C16.2, C21.2, C22.2, C23.2, C24.2, C25.2, C26.2, C27.2, C28.2, C29.2, C30.2, C31.2, C32.2, C33.2, C34.2, C35.2, C36.2, C37.2, C38.2, C39.2, C40.2, C41.2, C42.2, C43.2, C44.2, D1.2 (A), D2.2 (A), D3.1 (VDD), D4.1 (VDD), D5.1 (VDD), D6.1 (VDD), D7.1 (VDD), D8.1 (VDD), D9.1 (VDD), D10.1 (VDD), D11.1 (VDD), D12.1 (VDD), D13.1 (VDD), D14.1 (VDD), D15.1 (VDD), D16.1 (VDD), D17.1 (VDD), D18.1 (VDD), D19.1 (VDD), D20.1 (VDD), D21.1 (VDD), D22.1 (VDD), D23.1 (VDD), D24.1 (VDD), D25.1 (VDD), D26.1 (VDD), J4.1, R19.1, U1.3 (VI), U2.4 (VOUT), U4.3 (VI)
+7V: C3.1, C4.1, C6.1, J1.1, R1.1, R2.1, U2.2 (VCC), U3.2 (VCC)
BALL_MCU_RUN: J16.3, SW2.2
BALL_USB_BOOT: J10.4, SW1.2
BallUSB_D+: J8.A6 (DP1), J8.B6 (DP2), J10.2
BallUSB_D-: J8.A7 (DN1), J8.B7 (DN2), J10.1
ESC_PWM9: J5.11, Motor_1.1
GND: BZ1.2 (-), C1.2, C2.2, C3.2, C4.2, C5.2, C6.2, C7.2, C8.2, C9.2, C12.1, C13.1, C14.1, C15.1, C16.1, C17.2, C18.2, C19.2, C20.2, C21.1, C22.1, C23.1, C24.1, C25.1, C26.1, C27.1, C28.1, C29.1, C30.1, C31.1, C32.1, C33.1, C34.1, C35.1, C36.1, C37.1, C38.1, C39.1, C40.1, C41.1, C42.1, C43.1, C44.1, D3.3 (VSS), D4.3 (VSS), D5.3 (VSS), D6.3 (VSS), D7.3 (VSS), D8.3 (VSS), D9.3 (VSS), D10.3 (VSS), D11.3 (VSS), D12.3 (VSS), D13.3 (VSS), D14.3 (VSS), D15.3 (VSS), D16.3 (VSS), D17.3 (VSS), D18.3 (VSS), D19.3 (VSS), D20.3 (VSS), D21.3 (VSS), D22.3 (VSS), D23.3 (VSS), D24.3 (VSS), D25.3 (VSS), D26.3 (VSS), J1.2, J2.1, J4.2, J4.15, J5.1, J6.A1, J6.A1_B12 (GND), J6.A12, J6.B1, J6.B1_A12 (GND), J6.B12, J6.S1 (SHIELD), J6.S2 (SHIELD), J6.S3 (SHIELD), J6.S4 (SHIELD), J8.A1, J8.A1_B12 (GND), J8.A12, J8.B1, J8.B1_A12 (GND), J8.B12, J8.S1 (SHIELD), J8.S2 (SHIELD), J8.S3 (SHIELD), J8.S4 (SHIELD), J9.A1, J9.A1_B12 (GND), J9.A12, J9.B1, J9.B1_A12 (GND), J9.B12, J9.S1 (SHIELD), J9.S2 (SHIELD), J9.S3 (SHIELD), J9.S4 (SHIELD), J11.4, J12.4, J13.3, J13.4, J14.4, J15.4, J17.1, R4.2, R5.2, R8.2, R9.2, R10.2, R11.2, R14.2, R16.2, R17.2, SW1.1, SW3.1, U1.1 (GND), U2.3 (GND), U2.6 (GND), U3.3 (GND), U3.6 (GND), U4.1 (GND), U6.13 (GND), U7.13 (GND), bno_1.2, cam_1.1, cam_2.1, cam_3.1, kick_1.1, led_1.2, tact_1.2, tact_2.2, tact_3.2, toggle_1.2 (B)
LINE_MCU_RUN: SW4.2, line_1.6
LINE_USB_BOOT: SW3.2, line_1.5
M1_D2: J5.4, Motor_1.6
M1_D3: J5.5, Motor_1.5
M2_D4: J5.6, Motor_1.4
M2_D5: J5.7, Motor_1.3
MRESET_D6: J5.8, Motor_1.2
Neopix: R18.2, U7.9 (PA7_A8_D8_SCK), neopix1.2 (S)
unnamed: D1.1 (K), U6.14 (5V)
unnamed: D2.1 (K), U7.14 (5V)
unnamed: D3.4 (DIN), R19.2, neopix1.3 (D)
unnamed: D3.2 (DOUT), D4.4 (DIN)
unnamed: D4.2 (DOUT), D5.4 (DIN)
unnamed: D5.2 (DOUT), D6.4 (DIN)
unnamed: D6.2 (DOUT), D7.4 (DIN)
unnamed: D7.2 (DOUT), D8.4 (DIN)
unnamed: D8.2 (DOUT), D9.4 (DIN)
unnamed: D9.2 (DOUT), D10.4 (DIN)
unnamed: D10.2 (DOUT), D11.4 (DIN)
unnamed: D11.2 (DOUT), D12.4 (DIN)
unnamed: D12.2 (DOUT), D13.4 (DIN)
unnamed: D13.2 (DOUT), D14.4 (DIN)
unnamed: D14.2 (DOUT), D15.4 (DIN)
unnamed: D15.2 (DOUT), D16.4 (DIN)
unnamed: D16.2 (DOUT), D17.4 (DIN)
unnamed: D17.2 (DOUT), D18.4 (DIN)
unnamed: D18.2 (DOUT), D19.4 (DIN)
unnamed: D19.2 (DOUT), D20.4 (DIN)
unnamed: D20.2 (DOUT), D21.4 (DIN)
unnamed: D21.2 (DOUT), D22.4 (DIN)
unnamed: D22.2 (DOUT), D23.4 (DIN)
unnamed: D23.2 (DOUT), D24.4 (DIN)
unnamed: D24.2 (DOUT), D25.4 (DIN)
unnamed: D25.2 (DOUT), D26.4 (DIN)
unnamed: J6.A5 (CC1), R4.1
unnamed: J6.B5 (CC2), R5.1
unnamed: J8.A5 (CC1), R8.1
unnamed: J8.B5 (CC2), R10.1
unnamed: J9.A5 (CC1), R9.1
unnamed: J9.B5 (CC2), R11.1
unnamed: R14.1, SW2.1
unnamed: R17.1, SW4.1
unnamed: R1.2, U2.1 (CTL)
unnamed: R2.2, U3.1 (CTL)
unnamed: R15.2, led_1.1
SCL_0: J4.8, R13.1, bno_1.4
SCL_OLED: J17.3, U7.6 (PA9_A5_D5_SCL)
SDA_0: J4.9, R12.1, bno_1.3
SDA_OLED: J17.4, U7.5 (PA8_A4_D4_SDA)
USS_back_1: J14.2, U6.3 (PA10_A2_D2)
USS_back_2: J14.3, U6.4 (PA11_A3_D3)
USS_flont_1: J11.2, U6.1 (PA02_A0_D0)
USS_flont_2: J11.3, U6.2 (PA4_A1_D1)
USS_left_1: J15.2, U6.9 (PA7_A8_D8_SCK)
USS_left_2: J15.3, U6.10 (PA5_A9_D9_MISO)
USS_right_1: J12.2, U6.5 (PA8_A4_D4_SDA)
USS_right_2: J12.3, U6.6 (PA9_A5_D5_SCL)
catch_A8: J4.5, R16.1, photo_1.2
getVCC_A9: J1.3, J4.4
kick_D31: J5.23, kick_1.2
kick_D32: J5.24, kick_1.3
line_D+: J6.A6 (DP1), J6.B6 (DP2), line_1.3
line_D-: J6.A7 (DN1), J6.B7 (DN2), line_1.4
mainRX1→lineTX: J5.2, line_1.2
mainRX2→cam1TX: J5.9, cam_1.3
mainRX3→ballTX: J4.12, J16.1
mainRX4→uiTX: J4.11, U7.7 (PB08_A6_D6_TX)
mainRX5→ussTX: J4.6, U6.7 (PB08_A6_D6_TX)
mainRX6→cam2TX: J5.17, cam_2.3
mainRX7→cam3TX: J5.20, cam_3.3
mainRX8→moduleTX: J3.3, J4.23
mainTX1→lineRX: J5.3, line_1.1
mainTX2→cam1RX: J5.10, cam_1.4
mainTX3→ballRX: J4.13, J16.2
mainTX4→uiRX: J4.10, U7.8 (PB09_A7_D7_RX)
mainTX5→ussRX: J4.7, U6.8 (PB09_A7_D7_RX)
mainTX6→cam2RX: J5.16, cam_2.4
mainTX7→cam3RX: J5.21, cam_3.4
mainTX8→modeleRX: J3.4, J4.22
main_D+: J9.A6 (DP1), J9.B6 (DP2), dpdm_1.2
main_Dー: J9.A7 (DN1), J9.B7 (DN2), dpdm_1.1
selectchannel_1: J3.5, J4.20
selectchannel_2: J3.6, J4.19
startsignal: J3.1, J4.21
tact_1: U7.3 (PA10_A2_D2), tact_1.1
tact_2: U7.2 (PA4_A1_D1), tact_2.1
tact_3: U7.1 (PA02_A0_D0), tact_3.1
togg: R3.2, U7.4 (PA11_A3_D3), toggle_1.1 (A)

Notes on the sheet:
SWITCHES
LINE TYPE-C
BNO055
BALL TYPE-C
Teensy4.1
NEOPIXELS
MAIN TYPE-C
MAX1A
MAIN_BOARD

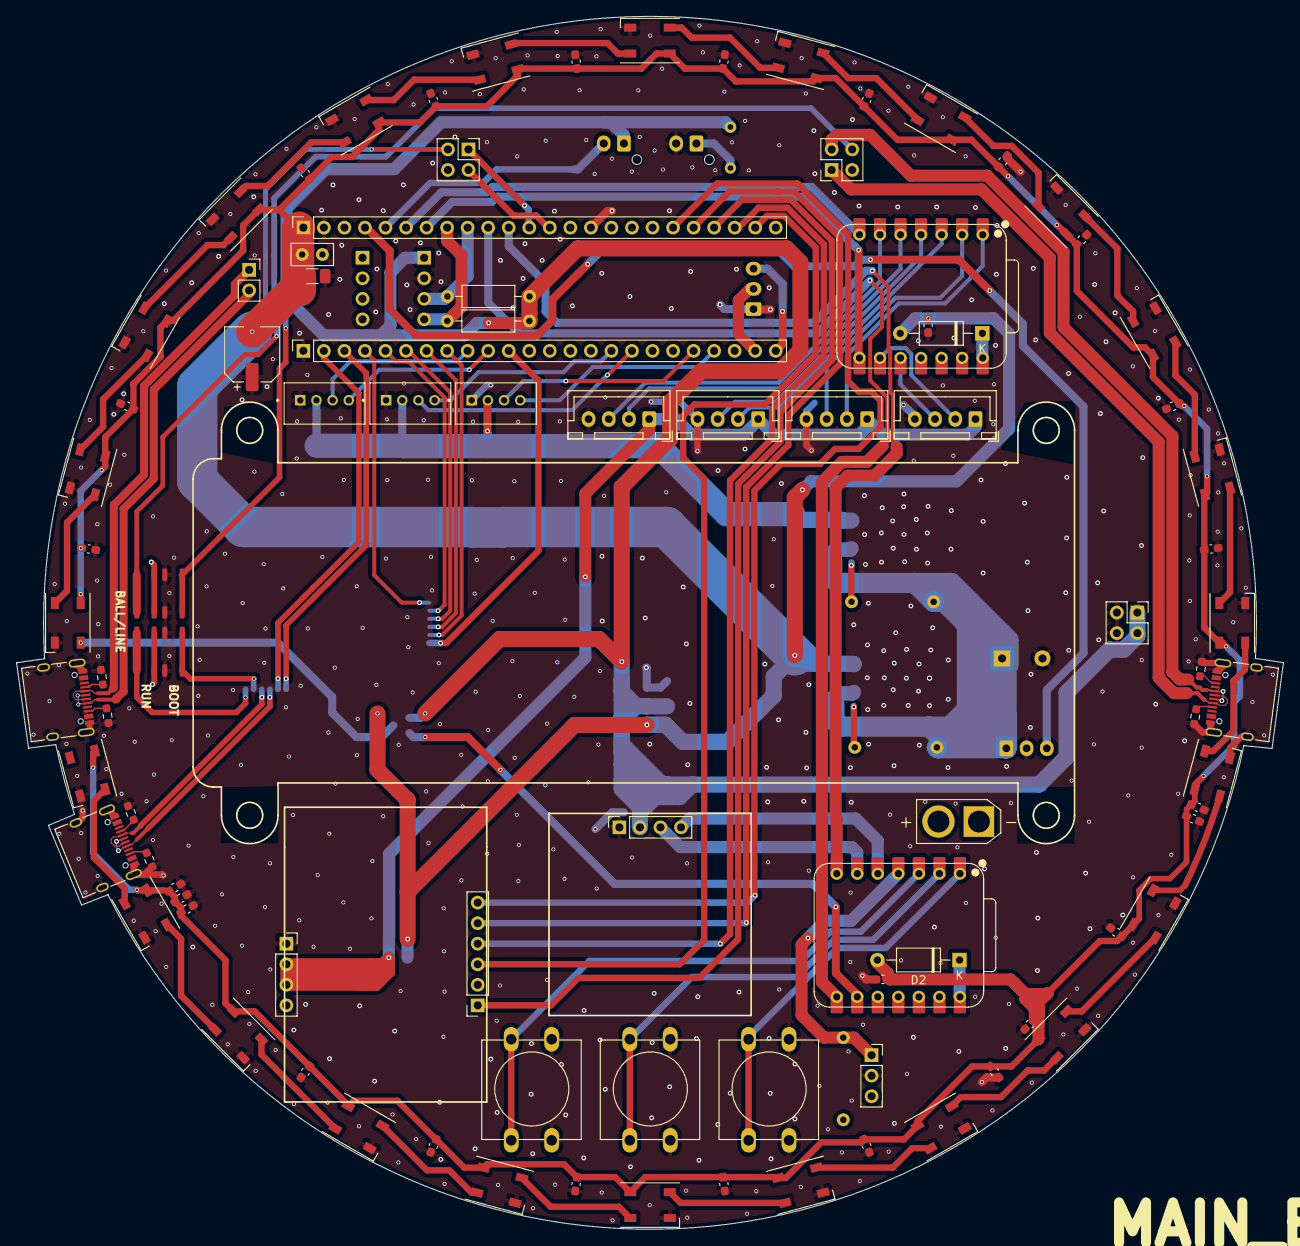
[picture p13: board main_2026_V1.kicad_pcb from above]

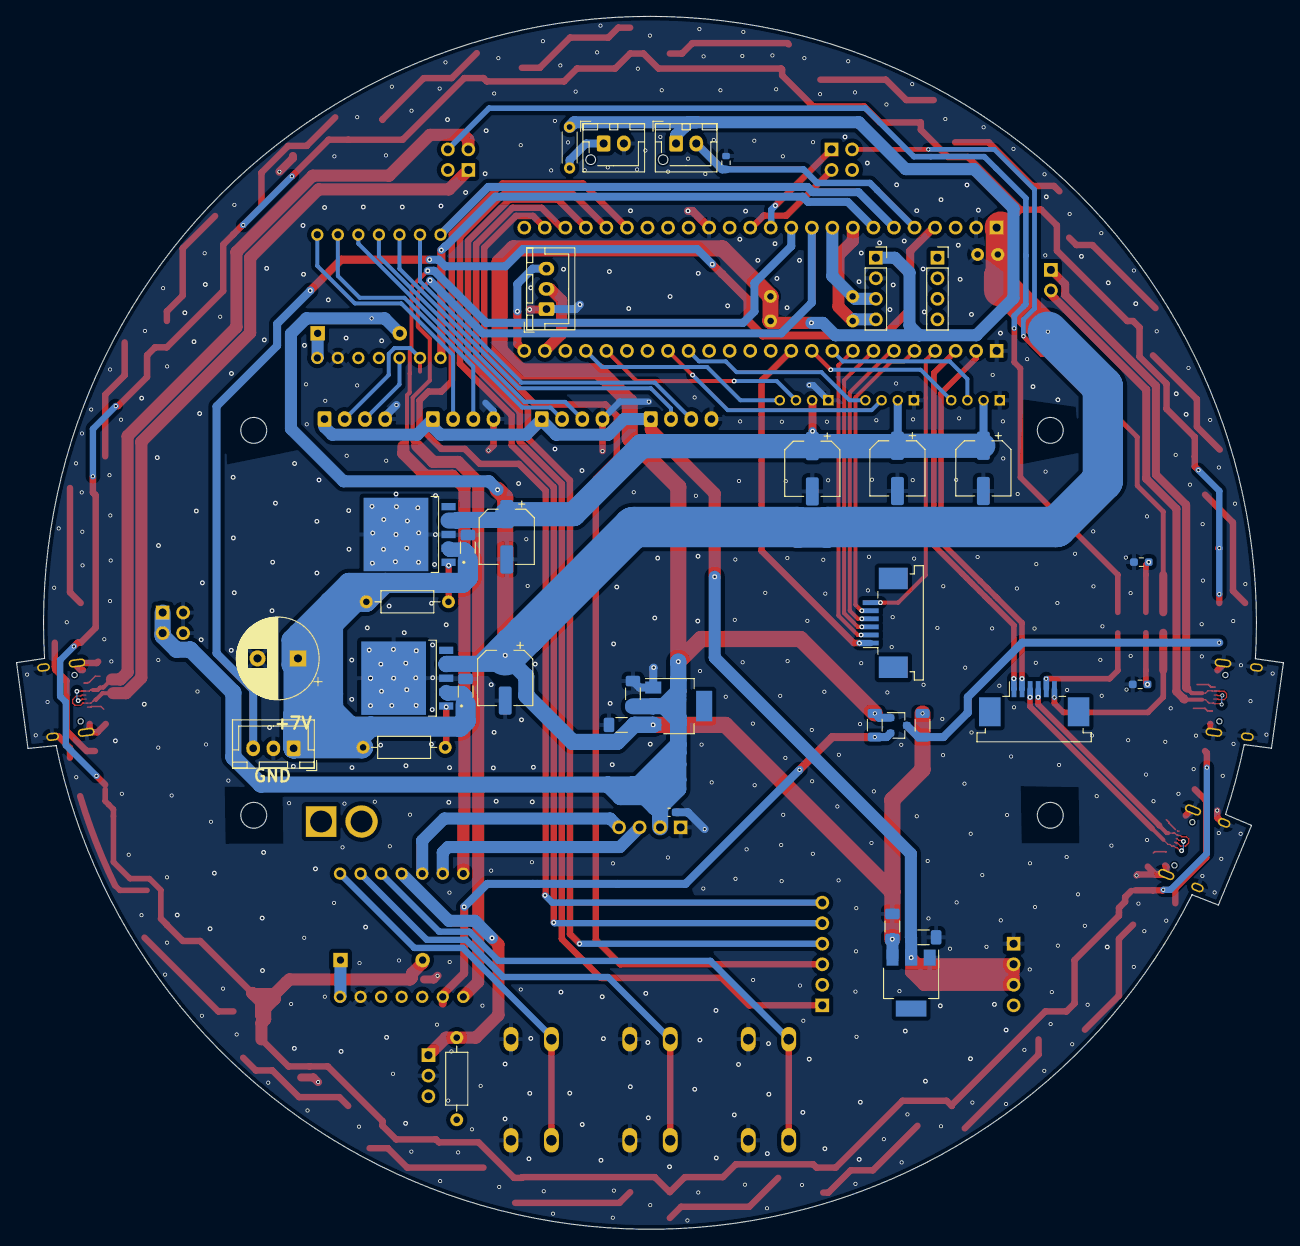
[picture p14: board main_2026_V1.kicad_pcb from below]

Board: 2 copper layers, 156.7 x 150.0 mm, 127 parts (35 on the bottom side), 99 nets.

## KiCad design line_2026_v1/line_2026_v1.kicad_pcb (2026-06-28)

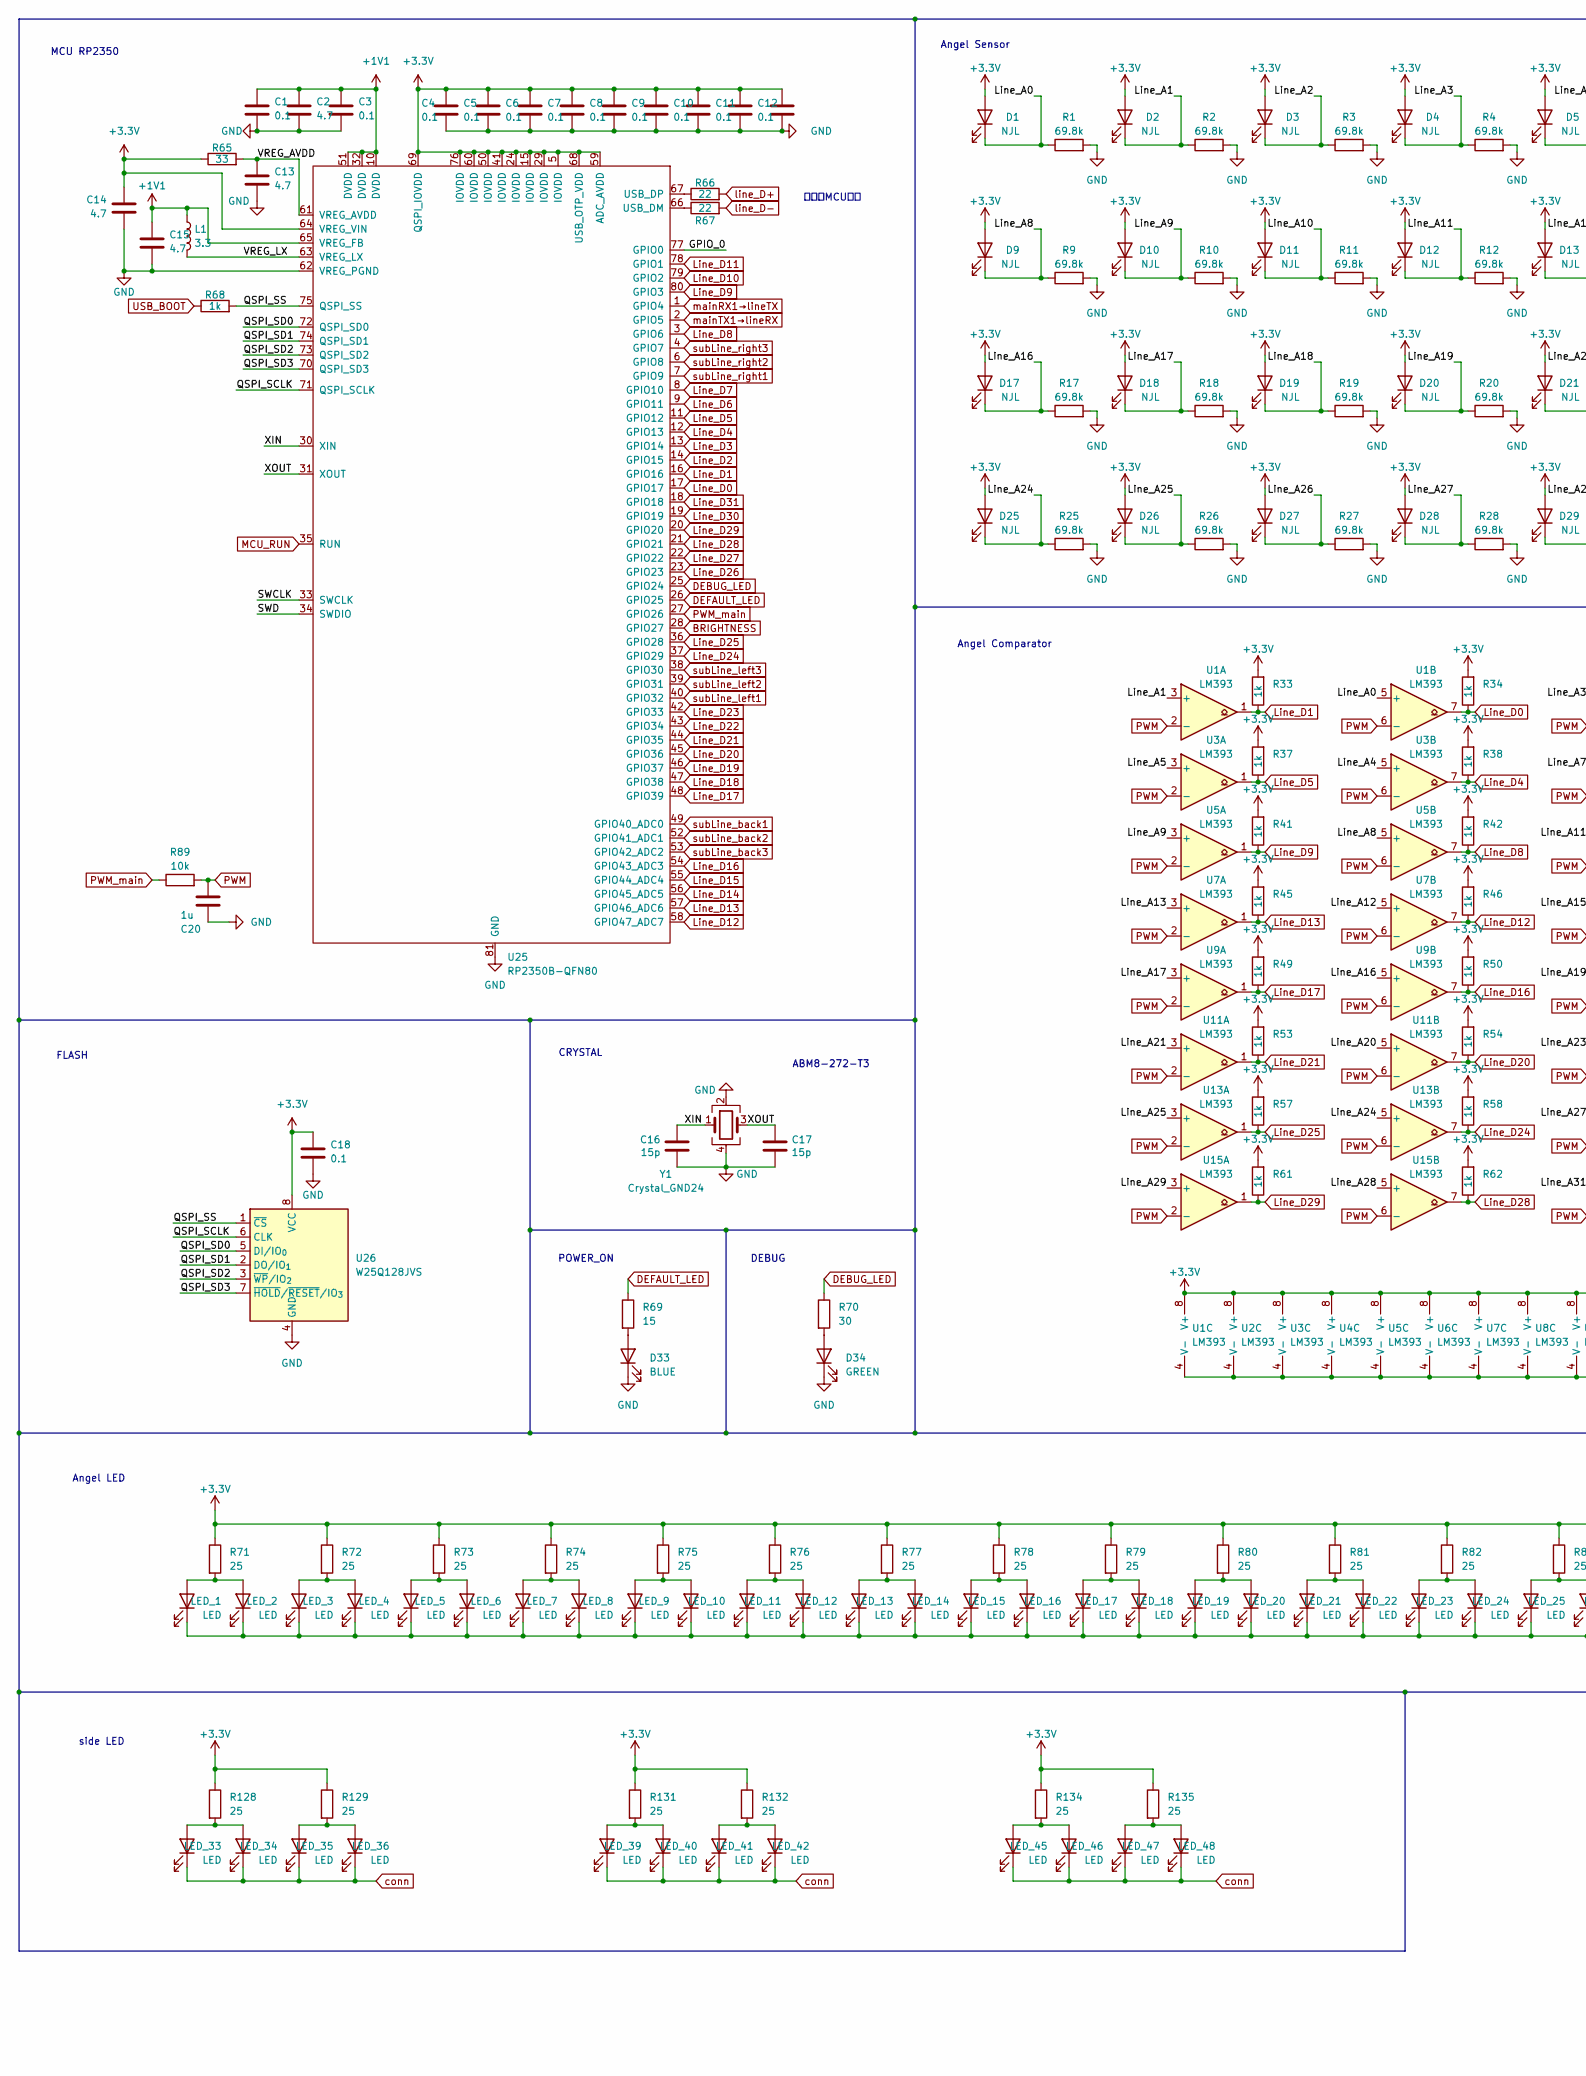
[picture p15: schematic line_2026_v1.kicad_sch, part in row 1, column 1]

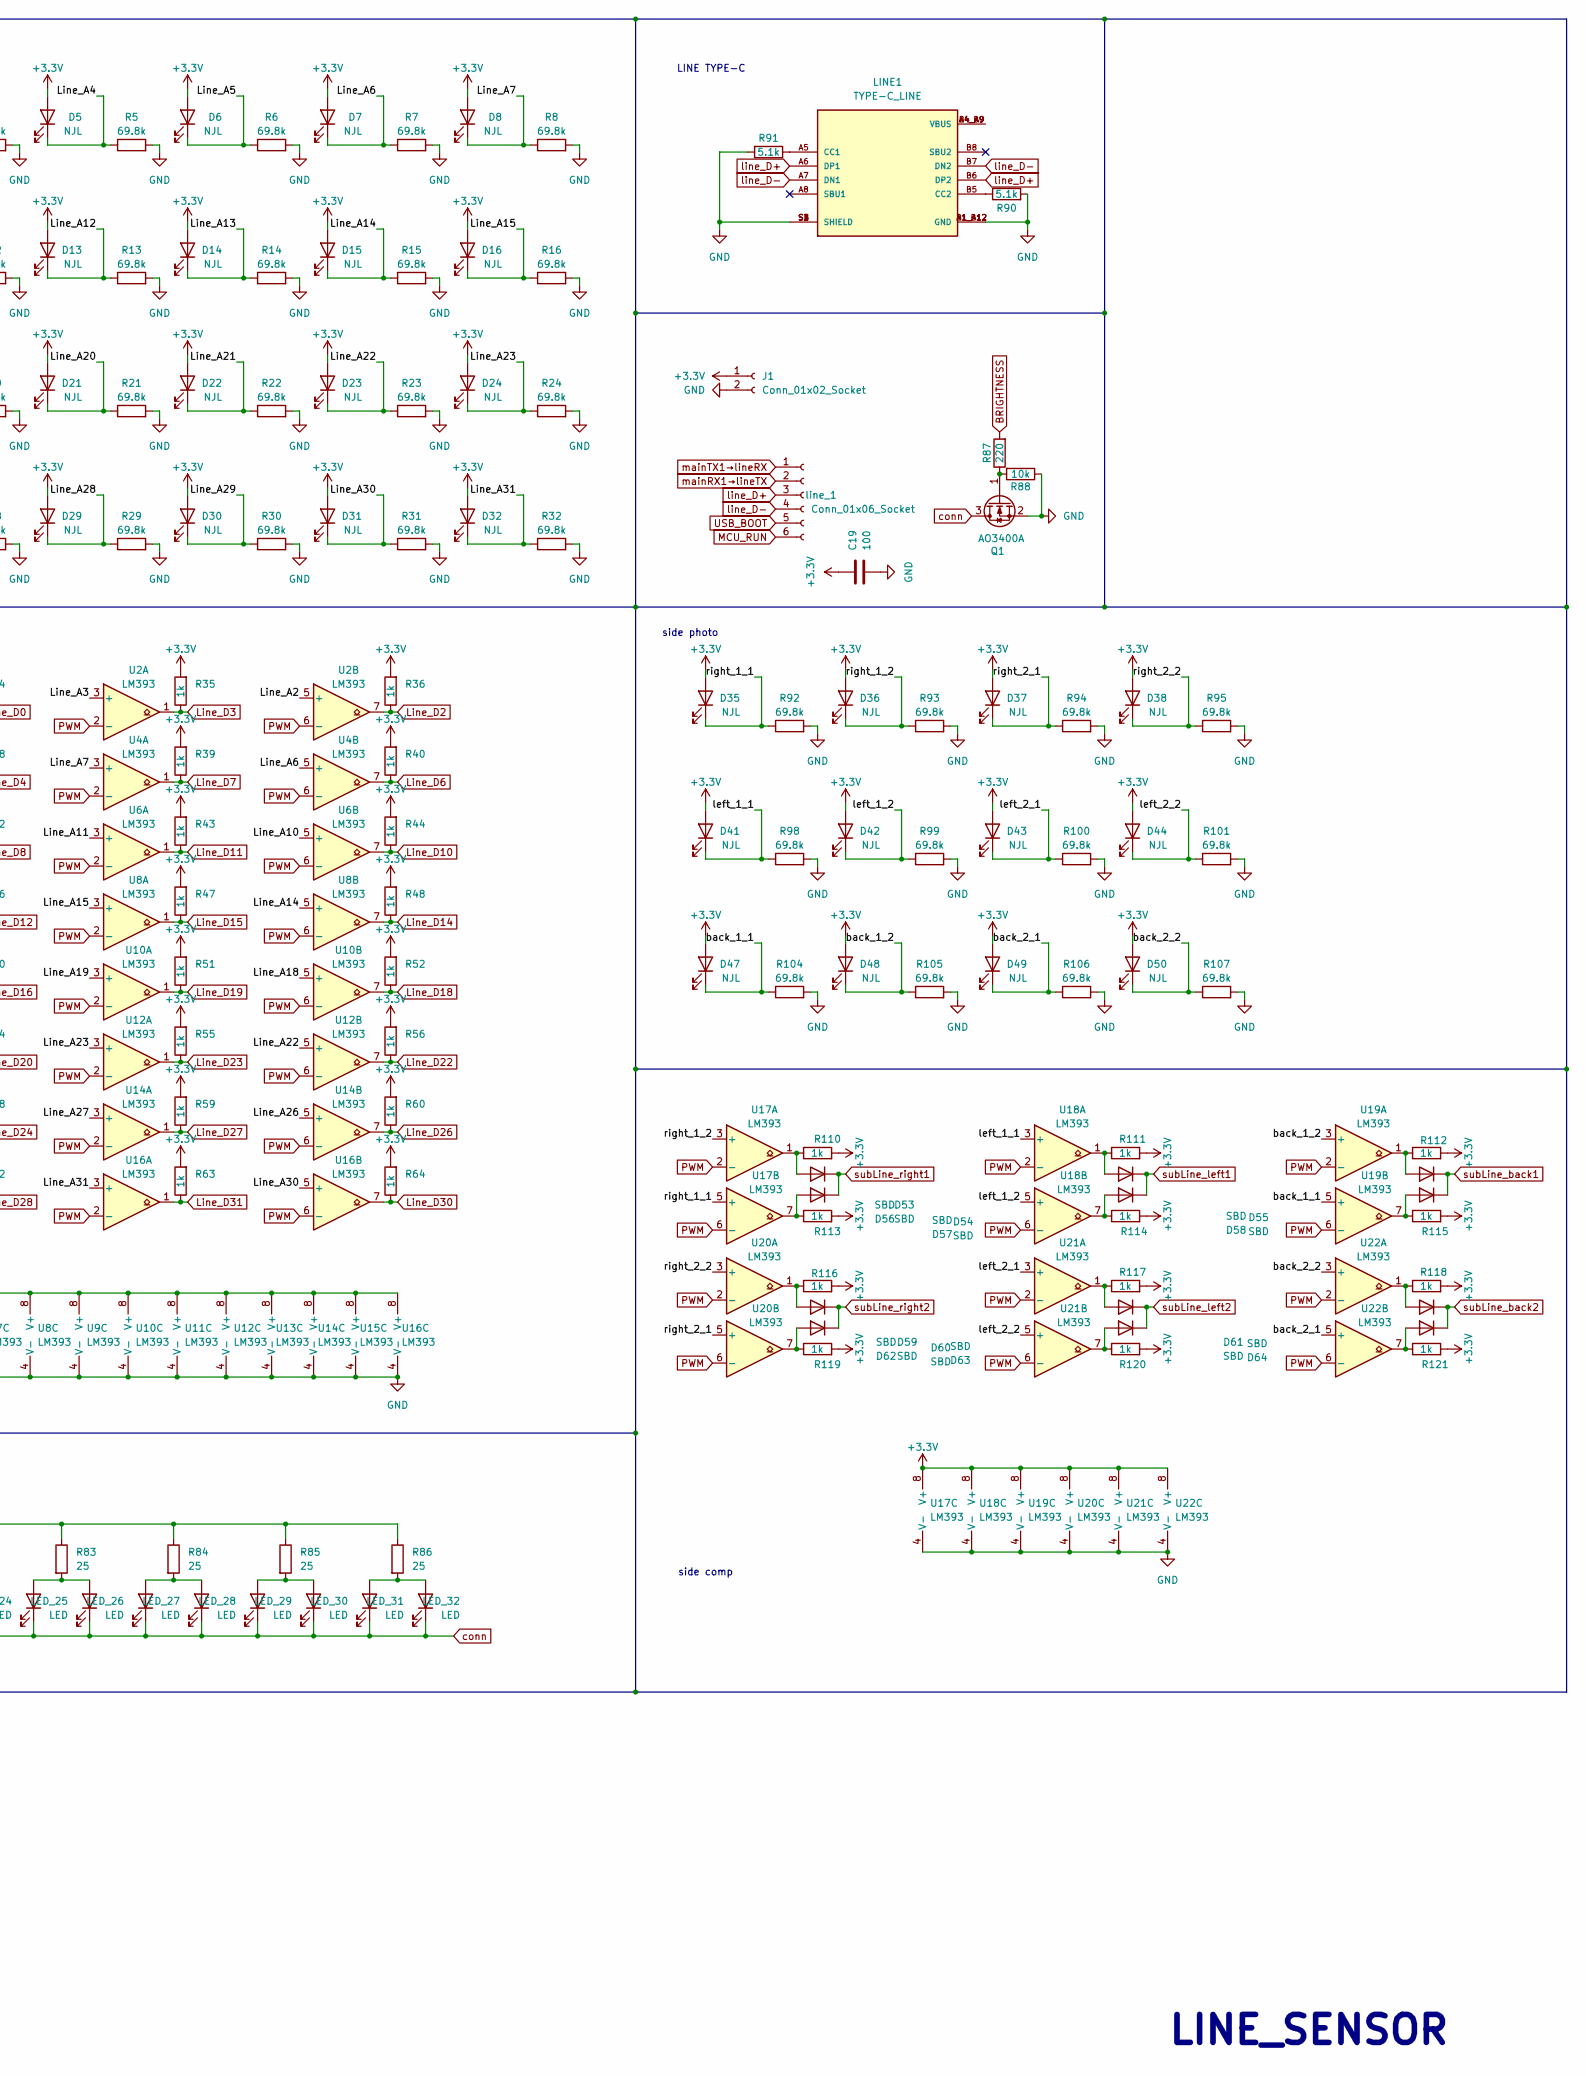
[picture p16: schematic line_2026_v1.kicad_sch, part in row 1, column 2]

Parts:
C1, C3, C4, C5, C6, C7, C8, C9, C10, C11, C12, C18: 0.1; C_0402_1005Metric
C2, C14, C15: 4.7; C_0402_1005Metric
C13: 4.7; C_0402_1005Metric; LCSC C1872
C16, C17: 15p; C_0402_1005Metric; LCSC C1548
C19: 100; CP_Elec_5x5.4
C20: 1u; C_Elec_4x5.4; LCSC C3348
D1, D2, D3, D4, D5, D6, D7, D8, D9, D10, D11, D12, D13, D14, D15, D16, D17, D18, D19, D20, D21, D22, D23, D24, D25, D26, D27, D28, D29, D30, D31, D32, D35, D36, D37, D38, D41, D42, D43, D44, D47, D48, D49, D50: NJL; LED_0603_1608Metric_Pad1.05x0.95mm_HandSolder
D33: BLUE; LED_0603_1608Metric_Pad1.05x0.95mm_HandSolder
D34: GREEN; LED_0603_1608Metric_Pad1.05x0.95mm_HandSolder
D53, D54, D55, D56, D57, D58, D59, D60, D61, D62, D63, D64: SBD; D_SOD-323
J1: Conn_01x02_Socket; JST_XH_S2B-XH-A_1x02_P2.50mm_Horizontal
L1: 3.3; Inductor_0806_2016; LCSC C42411119
LED_1, LED_2, LED_3, LED_4, LED_5, LED_6, LED_7, LED_8, LED_9, LED_10, LED_11, LED_12, LED_13, LED_14, LED_15, LED_16, LED_17, LED_18, LED_19, LED_20, LED_21, LED_22, LED_23, LED_24, LED_25, LED_26, LED_27, LED_28, LED_29, LED_30, LED_31, LED_32, LED_33, LED_34, LED_35, LED_36, LED_39, LED_40, LED_41, LED_42, LED_45, LED_46, LED_47, LED_48: LED; LED_0603_1608Metric_Pad1.05x0.95mm_HandSolder
LINE1: TYPE-C_LINE; USB_C_Receptacle_XKB_U262-16XN-4BVC11; PARTREV B
Q1: AO3400A; SOT-23
R1, R2, R3, R4, R5, R6, R7, R8, R9, R10, R11, R12, R13, R14, R15, R16, R17, R18, R19, R20, R21, R22, R23, R24, R25, R26, R27, R28, R29, R30, R31, R32, R92, R93, R94, R95, R98, R99, R100, R101, R104, R105, R106, R107: 69.8k; R_0603_1608Metric; LCSC C23098
R33, R34, R35, R36, R37, R38, R39, R40, R41, R42, R43, R44, R45, R46, R47, R48, R49, R50, R51, R52, R53, R54, R55, R56, R57, R58, R59, R60, R61, R62, R63, R64, R110, R111, R112, R113, R114, R115, R116, R117, R118, R119, R120, R121: 1k; R_0603_1608Metric; LCSC C23098
R65: 33; R_0603_1608Metric; LCSC C177281
R66: 22; R_0402_1005Metric; LCSC C174144
R67: 22; R_0402_1005Metric
R68: 1k; R_0402_1005Metric; LCSC C174178
R69: 15; R_0402_1005Metric; LCSC C22369173
R70: 30; R_0402_1005Metric; LCSC C22356186
R71, R72, R73, R74, R75, R76, R77, R78, R79, R80, R81, R82, R83, R84, R85, R86, R128, R129, R131, R132, R134, R135: 25; R_0603_1608Metric
R87: 220; R_0805_2012Metric
R88: 10k; R_0603_1608Metric
R89: 10k; R_0603_1608Metric; LCSC C23098
R90, R91: 5.1k; R_0603_1608Metric_Pad0.98x0.95mm_HandSolder; LCSC C26033
U1, U2, U3, U4, U5, U6, U7, U8, U9, U10, U11, U12, U13, U14, U15, U16, U17, U18, U19, U20, U21, U22: LM393; SOIC-8_3.9x4.9mm_P1.27mm
U25: RP2350B-QFN80; RP2350B_QFN-80_EP_10.573x10.573_Pitch0.4mm
U26: W25Q128JVS; SOIC-8_5.23x5.23mm_P1.27mm
Y1: Crystal_GND24; Crystal_SMD_3225-4Pin_3.2x2.5mm; LCSC C20625731
line_1: Conn_01x06_Socket; TE_84952-6_1x06-1MP_P1.0mm_Horizontal

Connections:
+1V1: C1.1, C2.1, C3.1, C15.1, L1.1, U25.10 (DVDD), U25.32 (DVDD), U25.51 (DVDD), U25.65 (VREG_FB)
+3.3V: C4.1, C5.1, C6.1, C7.1, C8.1, C9.1, C10.1, C11.1, C12.1, C14.1, C18.1, C19.1, D1.2 (A), D2.2 (A), D3.2 (A), D4.2 (A), D5.2 (A), D6.2 (A), D7.2 (A), D8.2 (A), D9.2 (A), D10.2 (A), D11.2 (A), D12.2 (A), D13.2 (A), D14.2 (A), D15.2 (A), D16.2 (A), D17.2 (A), D18.2 (A), D19.2 (A), D20.2 (A), D21.2 (A), D22.2 (A), D23.2 (A), D24.2 (A), D25.2 (A), D26.2 (A), D27.2 (A), D28.2 (A), D29.2 (A), D30.2 (A), D31.2 (A), D32.2 (A), D35.2 (A), D36.2 (A), D37.2 (A), D38.2 (A), D41.2 (A), D42.2 (A), D43.2 (A), D44.2 (A), D47.2 (A), D48.2 (A), D49.2 (A), D50.2 (A), J1.1, R33.2, R34.2, R35.2, R36.2, R37.2, R38.2, R39.2, R40.2, R41.2, R42.2, R43.2, R44.2, R45.2, R46.2, R47.2, R48.2, R49.2, R50.2, R51.2, R52.2, R53.2, R54.2, R55.2, R56.2, R57.2, R58.2, R59.2, R60.2, R61.2, R62.2, R63.2, R64.2, R65.1, R71.1, R72.1, R73.1, R74.1, R75.1, R76.1, R77.1, R78.1, R79.1, R80.1, R81.1, R82.1, R83.1, R84.1, R85.1, R86.1, R110.2, R111.2, R112.2, R113.2, R114.2, R115.2, R116.2, R117.2, R118.2, R119.2, R120.2, R121.2, R128.1, R129.1, R131.1, R132.1, R134.1, R135.1, U1.8 (V+), U2.8 (V+), U3.8 (V+), U4.8 (V+), U5.8 (V+), U6.8 (V+), U7.8 (V+), U8.8 (V+), U9.8 (V+), U10.8 (V+), U11.8 (V+), U12.8 (V+), U13.8 (V+), U14.8 (V+), U15.8 (V+), U16.8 (V+), U17.8 (V+), U18.8 (V+), U19.8 (V+), U20.8 (V+), U21.8 (V+), U22.8 (V+), U25.5 (IOVDD), U25.15 (IOVDD), U25.24 (IOVDD), U25.29 (IOVDD), U25.41 (IOVDD), U25.50 (IOVDD), U25.59 (ADC_AVDD), U25.60 (IOVDD), U25.64 (VREG_VIN), U25.68 (USB_OTP_VDD), U25.69 (QSPI_IOVDD), U25.76 (IOVDD), U26.8 (VCC)
/GPIO_0: U25.77 (GPIO0)
/Line_A0: D1.1 (K), R1.1, U1.5 (+)
/Line_A1: D2.1 (K), R2.1, U1.3 (+)
/Line_A2: D3.1 (K), R3.1, U2.5 (+)
/Line_A3: D4.1 (K), R4.1, U2.3 (+)
/Line_A4: D5.1 (K), R5.1, U3.5 (+)
/Line_A5: D6.1 (K), R6.1, U3.3 (+)
/Line_A6: D7.1 (K), R7.1, U4.5 (+)
/Line_A7: D8.1 (K), R8.1, U4.3 (+)
/Line_A8: D9.1 (K), R9.1, U5.5 (+)
/Line_A9: D10.1 (K), R10.1, U5.3 (+)
/Line_A10: D11.1 (K), R11.1, U6.5 (+)
/Line_A11: D12.1 (K), R12.1, U6.3 (+)
/Line_A12: D13.1 (K), R13.1, U7.5 (+)
/Line_A13: D14.1 (K), R14.1, U7.3 (+)
/Line_A14: D15.1 (K), R15.1, U8.5 (+)
/Line_A15: D16.1 (K), R16.1, U8.3 (+)
/Line_A16: D17.1 (K), R17.1, U9.5 (+)
/Line_A17: D18.1 (K), R18.1, U9.3 (+)
/Line_A18: D19.1 (K), R19.1, U10.5 (+)
/Line_A19: D20.1 (K), R20.1, U10.3 (+)
/Line_A20: D21.1 (K), R21.1, U11.5 (+)
/Line_A21: D22.1 (K), R22.1, U11.3 (+)
/Line_A22: D23.1 (K), R23.1, U12.5 (+)
/Line_A23: D24.1 (K), R24.1, U12.3 (+)
/Line_A24: D25.1 (K), R25.1, U13.5 (+)
/Line_A25: D26.1 (K), R26.1, U13.3 (+)
/Line_A26: D27.1 (K), R27.1, U14.5 (+)
/Line_A27: D28.1 (K), R28.1, U14.3 (+)
/Line_A28: D29.1 (K), R29.1, U15.5 (+)
/Line_A29: D30.1 (K), R30.1, U15.3 (+)
/Line_A30: D31.1 (K), R31.1, U16.5 (+)
/Line_A31: D32.1 (K), R32.1, U16.3 (+)
/QSPI_SCLK: U25.71 (QSPI_SCLK), U26.6 (CLK)
/QSPI_SD0: U25.72 (QSPI_SD0), U26.5 (DI/IO_{0})
/QSPI_SD1: U25.74 (QSPI_SD1), U26.2 (DO/IO_{1})
/QSPI_SD2: U25.73 (QSPI_SD2), U26.3 (~WP/IO_{2})
/QSPI_SD3: U25.70 (QSPI_SD3), U26.7 (~HOLD/~RESET/IO_{3})
/QSPI_SS: R68.2, U25.75 (QSPI_SS), U26.1 (~CS)
/SWCLK: U25.33 (SWCLK)
/SWD: U25.34 (SWDIO)
/VREG_AVDD: C13.1, R65.2, U25.61 (VREG_AVDD)
/VREG_LX: L1.2, U25.63 (VREG_LX)
/XIN: C16.1, U25.30 (XIN), Y1.1
/XOUT: C17.1, U25.31 (XOUT), Y1.3
/back_1_1: D47.1 (K), R104.1, U19.5 (+)
/back_1_2: D48.1 (K), R105.1, U19.3 (+)
/back_2_1: D49.1 (K), R106.1, U22.5 (+)
/back_2_2: D50.1 (K), R107.1, U22.3 (+)
/left_1_1: D41.1 (K), R98.1, U18.3 (+)
/left_1_2: D42.1 (K), R99.1, U18.5 (+)
/left_2_1: D43.1 (K), R100.1, U21.3 (+)
/left_2_2: D44.1 (K), R101.1, U21.5 (+)
/right_1_1: D35.1 (K), R92.1, U17.5 (+)
/right_1_2: D36.1 (K), R93.1, U17.3 (+)
/right_2_1: D37.1 (K), R94.1, U20.5 (+)
/right_2_2: D38.1 (K), R95.1, U20.3 (+)
BRIGHTNESS: R87.2, U25.28 (GPIO27)
DEBUG_LED: R70.1, U25.25 (GPIO24)
DEFAULT_LED: R69.1, U25.26 (GPIO25)
GND: C1.2, C2.2, C3.2, C4.2, C5.2, C6.2, C7.2, C8.2, C9.2, C10.2, C11.2, C12.2, C13.2, C14.2, C15.2, C16.2, C17.2, C18.2, C19.2, C20.2, D33.1 (K), D34.1 (K), J1.2, LINE1.A1, LINE1.A1_B12 (GND), LINE1.A12, LINE1.B1, LINE1.B1_A12 (GND), LINE1.B12, LINE1.S1 (SHIELD), LINE1.S2 (SHIELD), LINE1.S3 (SHIELD), LINE1.S4 (SHIELD), Q1.2 (S), R1.2, R2.2, R3.2, R4.2, R5.2, R6.2, R7.2, R8.2, R9.2, R10.2, R11.2, R12.2, R13.2, R14.2, R15.2, R16.2, R17.2, R18.2, R19.2, R20.2, R21.2, R22.2, R23.2, R24.2, R25.2, R26.2, R27.2, R28.2, R29.2, R30.2, R31.2, R32.2, R88.1, R90.2, R91.2, R92.2, R93.2, R94.2, R95.2, R98.2, R99.2, R100.2, R101.2, R104.2, R105.2, R106.2, R107.2, U1.4 (V-), U2.4 (V-), U3.4 (V-), U4.4 (V-), U5.4 (V-), U6.4 (V-), U7.4 (V-), U8.4 (V-), U9.4 (V-), U10.4 (V-), U11.4 (V-), U12.4 (V-), U13.4 (V-), U14.4 (V-), U15.4 (V-), U16.4 (V-), U17.4 (V-), U18.4 (V-), U19.4 (V-), U20.4 (V-), U21.4 (V-), U22.4 (V-), U25.62 (VREG_PGND), U25.81 (GND), U26.4 (GND), Y1.2, Y1.4
Line_D0: R34.1, U1.7, U25.17 (GPIO17)
Line_D1: R33.1, U1.1, U25.16 (GPIO16)
Line_D2: R36.1, U2.7, U25.14 (GPIO15)
Line_D3: R35.1, U2.1, U25.13 (GPIO14)
Line_D4: R38.1, U3.7, U25.12 (GPIO13)
Line_D5: R37.1, U3.1, U25.11 (GPIO12)
Line_D6: R40.1, U4.7, U25.9 (GPIO11)
Line_D7: R39.1, U4.1, U25.8 (GPIO10)
Line_D8: R42.1, U5.7, U25.3 (GPIO6)
Line_D9: R41.1, U5.1, U25.80 (GPIO3)
Line_D10: R44.1, U6.7, U25.79 (GPIO2)
Line_D11: R43.1, U6.1, U25.78 (GPIO1)
Line_D12: R46.1, U7.7, U25.58 (GPIO47_ADC7)
Line_D13: R45.1, U7.1, U25.57 (GPIO46_ADC6)
Line_D14: R48.1, U8.7, U25.56 (GPIO45_ADC5)
Line_D15: R47.1, U8.1, U25.55 (GPIO44_ADC4)
Line_D16: R50.1, U9.7, U25.54 (GPIO43_ADC3)
Line_D17: R49.1, U9.1, U25.48 (GPIO39)
Line_D18: R52.1, U10.7, U25.47 (GPIO38)
Line_D19: R51.1, U10.1, U25.46 (GPIO37)
Line_D20: R54.1, U11.7, U25.45 (GPIO36)
Line_D21: R53.1, U11.1, U25.44 (GPIO35)
Line_D22: R56.1, U12.7, U25.43 (GPIO34)
Line_D23: R55.1, U12.1, U25.42 (GPIO33)
Line_D24: R58.1, U13.7, U25.37 (GPIO29)
Line_D25: R57.1, U13.1, U25.36 (GPIO28)
Line_D26: R60.1, U14.7, U25.23 (GPIO23)
Line_D27: R59.1, U14.1, U25.22 (GPIO22)
Line_D28: R62.1, U15.7, U25.21 (GPIO21)
Line_D29: R61.1, U15.1, U25.20 (GPIO20)
Line_D30: R64.1, U16.7, U25.19 (GPIO19)
Line_D31: R63.1, U16.1, U25.18 (GPIO18)
MCU_RUN: U25.35 (RUN), line_1.6
unnamed: D33.2 (A), R69.2
unnamed: D34.2 (A), R70.2
unnamed: D53.2 (A), R110.1, U17.1
unnamed: D54.2 (A), R111.1, U18.1
unnamed: D55.2 (A), R112.1, U19.1
unnamed: D56.2 (A), R113.1, U17.7
unnamed: D57.2 (A), R114.1, U18.7
unnamed: D58.2 (A), R115.1, U19.7
unnamed: D59.2 (A), R116.1, U20.1
unnamed: D60.2 (A), R117.1, U21.1
unnamed: D61.2 (A), R118.1, U22.1
unnamed: D62.2 (A), R119.1, U20.7
unnamed: D63.2 (A), R120.1, U21.7
unnamed: D64.2 (A), R121.1, U22.7
unnamed: LED_1.2 (A), LED_2.2 (A), R71.2
unnamed: LED_3.2 (A), LED_4.2 (A), R72.2
unnamed: LED_5.2 (A), LED_6.2 (A), R73.2
unnamed: LED_7.2 (A), LED_8.2 (A), R74.2
unnamed: LED_9.2 (A), LED_10.2 (A), R75.2
unnamed: LED_11.2 (A), LED_12.2 (A), R76.2
unnamed: LED_13.2 (A), LED_14.2 (A), R77.2
unnamed: LED_15.2 (A), LED_16.2 (A), R78.2
unnamed: LED_17.2 (A), LED_18.2 (A), R79.2
unnamed: LED_19.2 (A), LED_20.2 (A), R80.2
unnamed: LED_21.2 (A), LED_22.2 (A), R81.2
unnamed: LED_23.2 (A), LED_24.2 (A), R82.2
unnamed: LED_25.2 (A), LED_26.2 (A), R83.2
unnamed: LED_27.2 (A), LED_28.2 (A), R84.2
unnamed: LED_29.2 (A), LED_30.2 (A), R85.2
unnamed: LED_31.2 (A), LED_32.2 (A), R86.2
unnamed: LED_33.2 (A), LED_34.2 (A), R128.2
unnamed: LED_35.2 (A), LED_36.2 (A), R129.2
unnamed: LED_39.2 (A), LED_40.2 (A), R131.2
unnamed: LED_41.2 (A), LED_42.2 (A), R132.2
unnamed: LED_45.2 (A), LED_46.2 (A), R134.2
unnamed: LED_47.2 (A), LED_48.2 (A), R135.2
unnamed: LINE1.A5 (CC1), R91.1
unnamed: LINE1.B5 (CC2), R90.1
unnamed: Q1.1 (G), R87.1, R88.2
unnamed: R67.1, U25.66 (USB_DM)
unnamed: R66.1, U25.67 (USB_DP)
PWM: C20.1, R89.2, U1.2 (-), U1.6 (-), U2.2 (-), U2.6 (-), U3.2 (-), U3.6 (-), U4.2 (-), U4.6 (-), U5.2 (-), U5.6 (-), U6.2 (-), U6.6 (-), U7.2 (-), U7.6 (-), U8.2 (-), U8.6 (-), U9.2 (-), U9.6 (-), U10.2 (-), U10.6 (-), U11.2 (-), U11.6 (-), U12.2 (-), U12.6 (-), U13.2 (-), U13.6 (-), U14.2 (-), U14.6 (-), U15.2 (-), U15.6 (-), U16.2 (-), U16.6 (-), U17.2 (-), U17.6 (-), U18.2 (-), U18.6 (-), U19.2 (-), U19.6 (-), U20.2 (-), U20.6 (-), U21.2 (-), U21.6 (-), U22.2 (-), U22.6 (-)
PWM_main: R89.1, U25.27 (GPIO26)
USB_BOOT: R68.1, line_1.5
conn: LED_1.1 (K), LED_2.1 (K), LED_3.1 (K), LED_4.1 (K), LED_5.1 (K), LED_6.1 (K), LED_7.1 (K), LED_8.1 (K), LED_9.1 (K), LED_10.1 (K), LED_11.1 (K), LED_12.1 (K), LED_13.1 (K), LED_14.1 (K), LED_15.1 (K), LED_16.1 (K), LED_17.1 (K), LED_18.1 (K), LED_19.1 (K), LED_20.1 (K), LED_21.1 (K), LED_22.1 (K), LED_23.1 (K), LED_24.1 (K), LED_25.1 (K), LED_26.1 (K), LED_27.1 (K), LED_28.1 (K), LED_29.1 (K), LED_30.1 (K), LED_31.1 (K), LED_32.1 (K), LED_33.1 (K), LED_34.1 (K), LED_35.1 (K), LED_36.1 (K), LED_39.1 (K), LED_40.1 (K), LED_41.1 (K), LED_42.1 (K), LED_45.1 (K), LED_46.1 (K), LED_47.1 (K), LED_48.1 (K), Q1.3 (D)
line_D+: LINE1.A6 (DP1), LINE1.B6 (DP2), R66.2, line_1.3
line_D-: LINE1.A7 (DN1), LINE1.B7 (DN2), R67.2, line_1.4
mainRX1→lineTX: U25.1 (GPIO4), line_1.2
mainTX1→lineRX: U25.2 (GPIO5), line_1.1
subLine_back1: D55.1 (K), D58.1 (K), U25.49 (GPIO40_ADC0)
subLine_back2: D61.1 (K), D64.1 (K), U25.52 (GPIO41_ADC1)
subLine_back3: U25.53 (GPIO42_ADC2)
subLine_left1: D54.1 (K), D57.1 (K), U25.40 (GPIO32)
subLine_left2: D60.1 (K), D63.1 (K), U25.39 (GPIO31)
subLine_left3: U25.38 (GPIO30)
subLine_right1: D53.1 (K), D56.1 (K), U25.7 (GPIO9)
subLine_right2: D59.1 (K), D62.1 (K), U25.6 (GPIO8)
subLine_right3: U25.4 (GPIO7)

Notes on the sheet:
side LED
FLASH
DEBUG
抵抗はMCU近く
CRYSTAL
side photo
LINE_SENSOR
Angel Comparator
POWER_ON
ABM8-272-T3
Angel Sensor
side comp
MCU RP2350
LINE TYPE-C
Angel LED

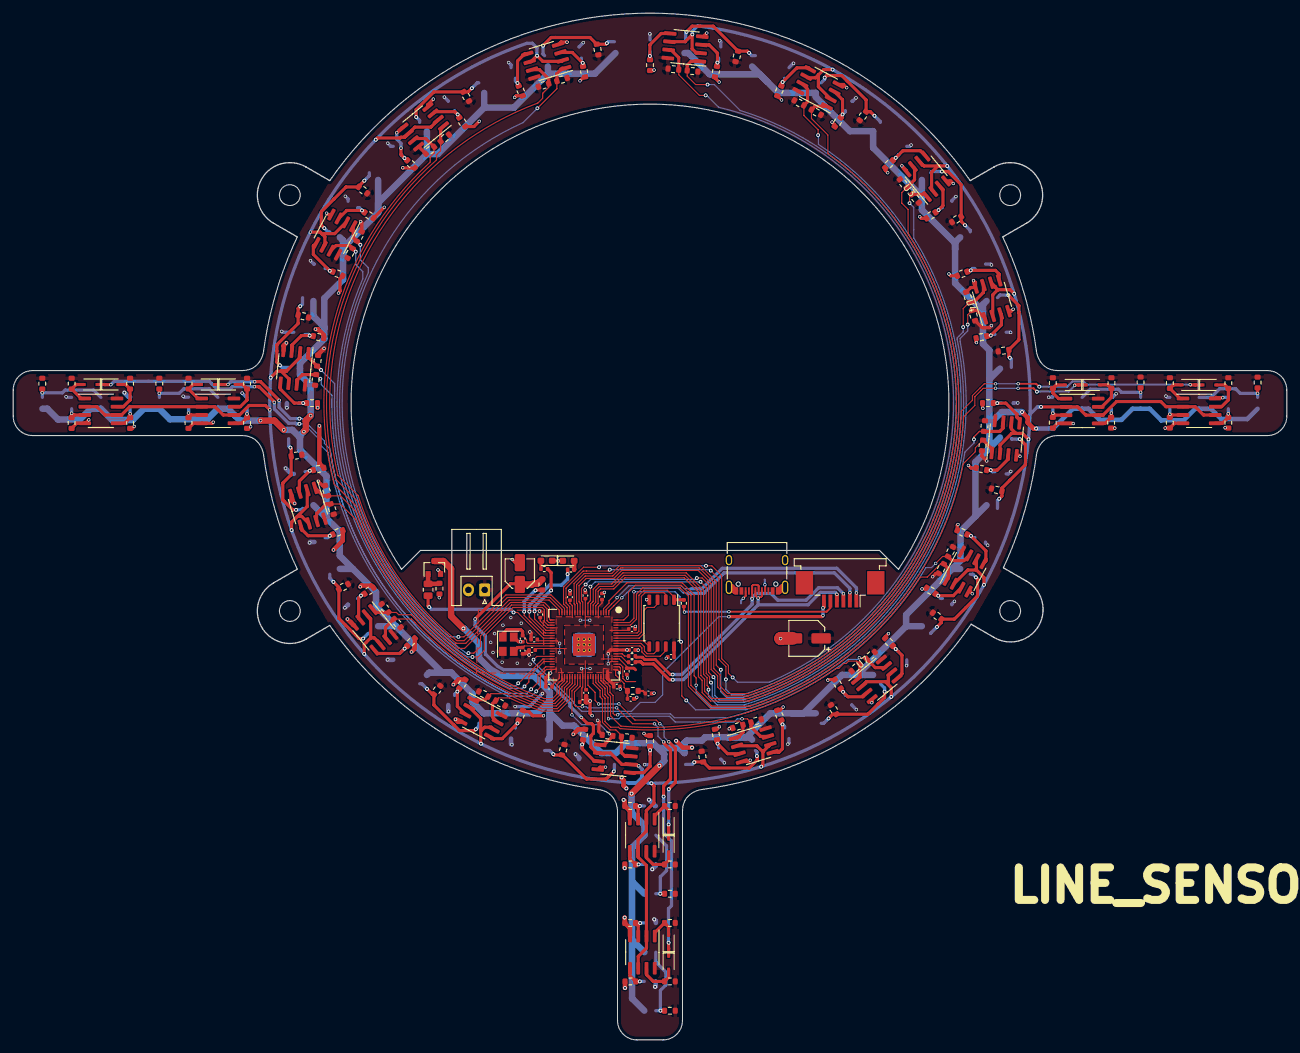
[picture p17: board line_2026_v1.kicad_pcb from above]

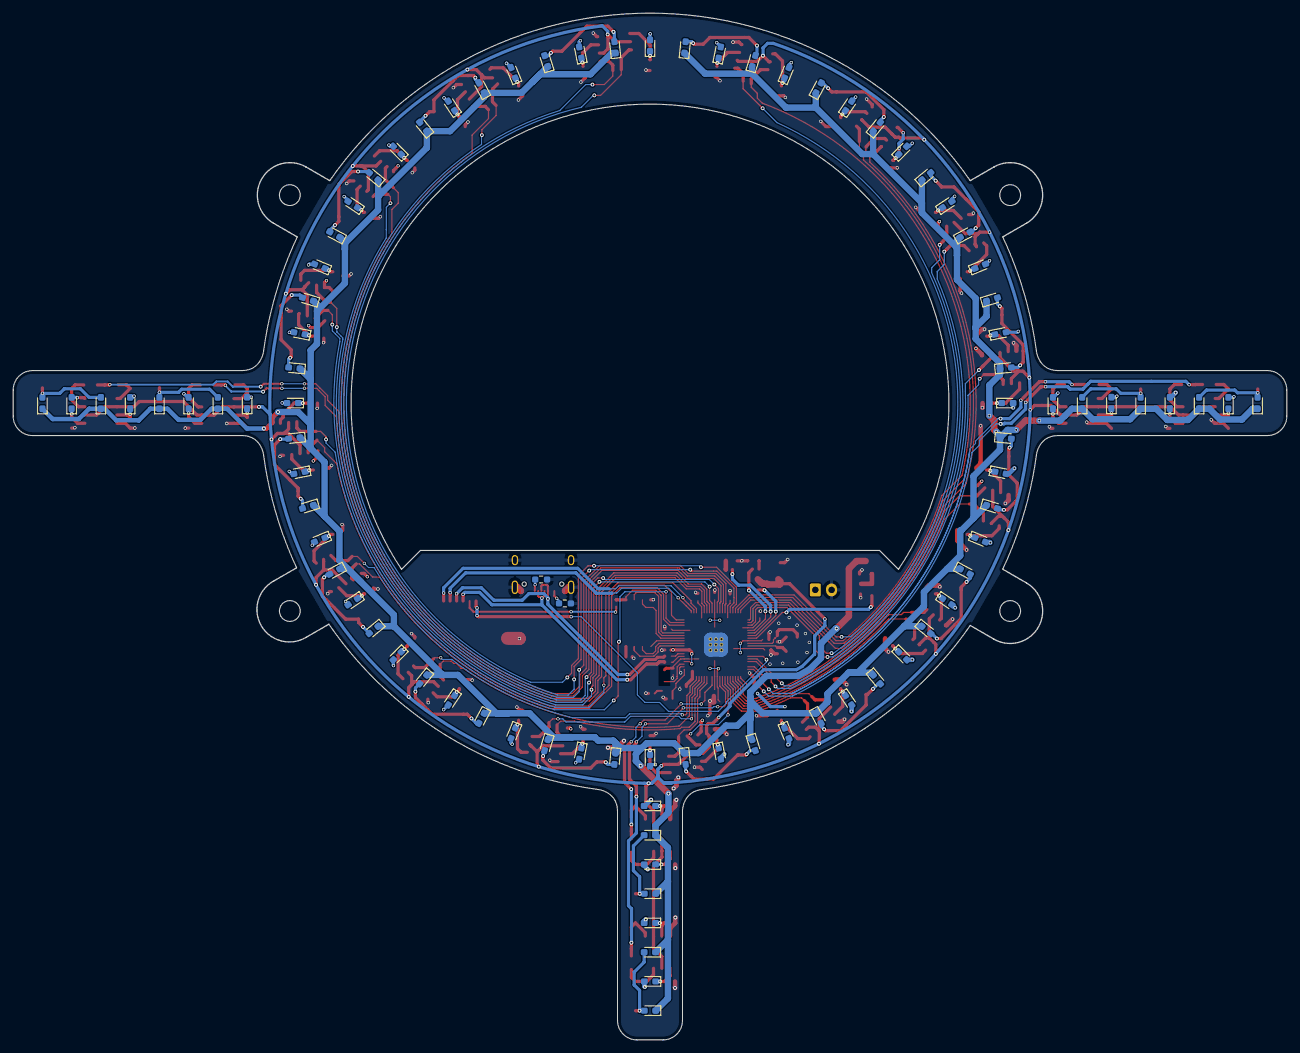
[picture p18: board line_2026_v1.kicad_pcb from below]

Board: 2 copper layers, 196.0 x 158.0 mm, 272 parts (90 on the bottom side), 147 nets.

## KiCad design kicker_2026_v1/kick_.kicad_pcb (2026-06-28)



Board: 2 copper layers, 76.1 x 45.5 mm, 26 parts (13 on the bottom side), 17 nets.

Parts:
D1: SBD; D_SOD-323_HandSoldering
D2: D; D_SOD-123F
D4: D; D_A-405_P10.16mm_Horizontal
H1, H1#2: MountingHole; MountingHole_3.2mm_M3
J1: Conn_01x02_Socket; JST_XH_S2B-XH-A_1x02_P2.50mm_Horizontal
J2, J3: Conn_01x02_Socket; PinSocket_1x02_P2.54mm_Vertical
J7, J8, J10, J11: Conn_01x01_Socket; PinSocket_1x01_P2.54mm_Vertical
K1: AQW212EHA; SMDIP-8_W7.62mm
LED_D1: LED; LED_0603_1608Metric_Pad1.05x0.95mm_HandSolder
Q1: PMOS; TO-252-2
Q2: NMOS; TO-220-3_Horizontal_TabDown
R1, R2: 1.6k; R_1206_3216Metric
R4: 1k; R_2512_6332Metric
R5: 3.3k; R_2512_6332Metric
R6: 150; R_2512_6332Metric
R9: 3k; R_2512_6332Metric
R10: 68; R_1206_3216Metric
R11: 10k; R_1206_3216Metric
main_1: Conn_01x03_Socket; JST_XH_S3B-XH-A_1x03_P2.50mm_Horizontal
sole1: Conn_01x02_Socket; JST_XH_S2B-XH-A_1x02_P2.50mm_Horizontal

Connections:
+12V: J1.1, J7.1, K1.5
+48V: D1.2 (A), J10.1
GND: J1.2, J2.2, J3.2, J8.1, J11.1, K1.7, LED_D1.1 (K), Q2.3 (S), R11.1
GND_MAIN: K1.2, K1.4, main_1.1
unnamed: D1.1 (K), D2.2 (A), Q1.3 (S), R4.1
unnamed: D2.1 (K), Q1.2 (D), R6.1
unnamed: D4.2 (A), Q2.1 (D), sole1.2
unnamed: D4.1 (K), J2.1, J3.1, R6.2, R9.1, sole1.1
unnamed: K1.1, R1.2
unnamed: K1.3, R2.2
unnamed: K1.6, R10.1
unnamed: K1.8, R5.1
unnamed: LED_D1.2 (A), R9.2
unnamed: Q1.1 (G), R4.2, R5.2
unnamed: Q2.2 (G), R10.2, R11.2
kick_1: R1.1, main_1.3
kick_2: R2.1, main_1.2

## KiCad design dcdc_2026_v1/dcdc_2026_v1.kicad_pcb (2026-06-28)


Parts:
C1, C7: 0.1; Capacitor_0402_1005
C2: 22; CP_Elec_5x5.4; LCSC C2887274
C3, C4, C9, C10, C11: 22; CP_Elec_5x5.4
C5: 10; CP_Elec_4x5.4; LCSC C2992602
C6: 2.7; CP_Elec_5x5.7
C8: 0.1; C_0603_1608Metric_Pad1.08x0.95mm_HandSolder
C12: 10; CP_Elec_4x5.4
C13: 2.7; CP_Elec_5x5.7; LCSC C487141
D1: D; D_SOD-123F
F1: Fuse; Fuseholder_Clip-5x20mm_Keystone_3517_Inline_P23.11x6.76mm_D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
J1: oled; PinSocket_1x02_P2.54mm_Vertical
J2: md; AMASS_XT30U-M_1x02_P5.0mm_Vertical
J3: Conn_01x03_Socket; JST_XH_S3B-XH-A_1x03_P2.50mm_Horizontal
J4: md_logic; JST_XH_S2B-XH-A_1x02_P2.50mm_Horizontal
J5: line; JST_XH_S2B-XH-A_1x02_P2.50mm_Horizontal
J6: kick; JST_XH_S2B-XH-A_1x02_P2.50mm_Horizontal
L1: 3.3; L_Bourns_SRP7028A_7.3x6.6mm
L2: 4.7; IND_ETQP5M4R7YFM
LiPo_1: XT30_IN; AMASS_XT30U-M_1x02_P5.0mm_Vertical
Q1: PMOS; TO-252-2
R1: 10k; R_Axial_DIN0207_L6.3mm_D2.5mm_P10.16mm_Horizontal
R2: 69.8k; R_0805_2012Metric; LCSC C17803
R3: 10.5k; R_0402_1005Metric; LCSC C25850
R4: 200k; R_0805_2012Metric; LCSC C17539
R5: 22.1k; R_0805_2012Metric
R6: 10k; R_Axial_DIN0207_L6.3mm_D2.5mm_P10.16mm_Horizontal; LCSC C26033
R7: 150k; R_0603_1608Metric; LCSC C177617
R8: 3.3k; R_Axial_DIN0207_L6.3mm_D2.5mm_P10.16mm_Horizontal; LCSC C26033
R9: 22k; R_0805_2012Metric
R10: 200k; R_0805_2012Metric
R11: 22.1k; R_0805_2012Metric; LCSC C17552
RV1: 50k; Potentiometer_Bourns_3314J_Vertical
SW1: SW_SPST; PinSocket_1x02_P2.54mm_Vertical
U1: AP64500SP-3.3v; SO-8EP_DIO
U2: AP64500SP-7v; SO-8EP_DIO

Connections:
+3.3V: C2.1, C3.1, C4.1, J4.1, J4.2, J5.1, L1.2, R2.2
+7V: C9.1, C10.1, C11.1, J3.1, L2.2, R7.2
GND: C2.2, C3.2, C4.2, C5.2, C6.2, C8.2, C9.2, C10.2, C11.2, C12.2, C13.2, J1.1, J2.1, J3.2, J5.2, J6.2, LiPo_1.1 (-), R4.2, R5.1, R8.2, R10.2, R11.1, SW1.1 (A), U1.7 (GND), U1.EPAD (GND), U2.7 (GND), U2.EPAD (GND)
unnamed: C6.1, R3.1
unnamed: C13.1, R9.1
unnamed: D1.1 (K), F1.2, Q1.3 (S), R1.1
unnamed: F1.1, LiPo_1.2 (+)
unnamed: Q1.1 (G), R1.2, SW1.2 (B)
unnamed: R7.1, RV1.1
unnamed: C1.1, U1.1 (BST)
unnamed: R3.2, U1.6 (COMP)
unnamed: R2.1, R5.2, U1.5 (FB)
unnamed: R4.1, U1.4 (RT/CLK)
unnamed: C1.2, L1.1, U1.8 (SW)
unnamed: C7.1, U2.1 (BST)
unnamed: R9.2, U2.6 (COMP)
unnamed: R11.2, RV1.2, RV1.3, U2.5 (FB)
unnamed: R10.1, U2.4 (RT/CLK)
unnamed: C7.2, L2.1, U2.8 (SW)
VCC: C5.1, C12.1, D1.2 (A), J1.2, J2.2, J6.1, Q1.2 (D), R6.1, U1.2 (VIN), U1.3 (EN), U2.2 (VIN), U2.3 (EN)
VOUT: C8.1, J3.3, R6.2, R8.1

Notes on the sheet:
POWER_DISTRIBUTION

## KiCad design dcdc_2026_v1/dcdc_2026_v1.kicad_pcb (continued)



Board: 2 copper layers, 76.1 x 45.5 mm, 43 parts (2 on the bottom side), 21 nets.

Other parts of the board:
H1, H1#2: MountingHole; MountingHole_3.2mm_M3
SW: rocker_SW; Rocker_SW

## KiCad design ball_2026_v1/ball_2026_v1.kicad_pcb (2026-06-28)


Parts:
A1, A2, A3, A4, A5, A6, A7, A8, A9, A10, A11, A12, A13, A14, A15, A16, A17, A18, A19, A20, A21, A22, A23, A24: TSSP4038; XDCR_TSSP4038; PARTREV 2.3
C1, C4, C16: 4.7; C_0402_1005Metric
C2, C5, C6, C7, C8, C9, C11, C12, C14, C15: 0.1; C_0402_1005Metric
C3: 4.7; C_0402_1005Metric; LCSC C1872
C10, C13: 15p; C_0402_1005Metric; LCSC C1548
C17: 150; CP_Elec_6.3x5.7; LCSC C249851
D1: BLUE; LED_0603_1608Metric_Pad1.05x0.95mm_HandSolder
D2: GREEN; LED_0603_1608Metric_Pad1.05x0.95mm_HandSolder
J1, J2, J3: Conn_02x02_Counter_Clockwise; PinHeader_2x02_P2.54mm_Vertical
L1: 3.3; Inductor_0806_2016; LCSC C42411119
R1: 15; R_0402_1005Metric; LCSC C22369173
R2: 30; R_0402_1005Metric; LCSC C22356186
R3: 1k; R_0402_1005Metric; LCSC C174178
R4: 33; R_0603_1608Metric; LCSC C177281
R6: 22; R_0402_1005Metric; LCSC C174144
R7: 22; R_0402_1005Metric
U1: W25Q128JVS; SOIC-8_5.23x5.23mm_P1.27mm
U2: RP2350_60QFN; Package_QFN-60-1EP_7x7mm_P0.4mm_EP3.4x3.4mm_hand
Y1: Crystal_GND24; Crystal_SMD_3225-4Pin_3.2x2.5mm; LCSC C20625731

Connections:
+1V1: C1.1, C2.1, C4.1, C5.1, L1.1, U2.6 (DVDD), U2.23 (DVDD), U2.39 (DVDD), U2.50 (VREG_FB)
+3.3V: A1.3 (VS), A2.3 (VS), A3.3 (VS), A4.3 (VS), A5.3 (VS), A6.3 (VS), A7.3 (VS), A8.3 (VS), A9.3 (VS), A10.3 (VS), A11.3 (VS), A12.3 (VS), A13.3 (VS), A14.3 (VS), A15.3 (VS), A16.3 (VS), A17.3 (VS), A18.3 (VS), A19.3 (VS), A20.3 (VS), A21.3 (VS), A22.3 (VS), A23.3 (VS), A24.3 (VS), C6.1, C7.1, C8.1, C9.1, C11.1, C12.1, C14.1, C15.1, C16.1, C17.1, J2.1, J2.2, R4.1, U1.8 (VCC), U2.1 (IOVDD), U2.11 (IOVDD), U2.20 (IOVDD), U2.30 (IOVDD), U2.38 (IOVDD), U2.44 (ADC_AVDD), U2.45 (IOVDD), U2.49 (VREG_VIN), U2.53 (USB_OTP_VDD), U2.54 (QSPI_IOVDD)
/GPIO_0: U2.2 (GPIO0)
/QSPI_SCLK: U1.6 (CLK), U2.56 (QSPI_SCLK)
/QSPI_SD0: U1.5 (DI/IO_{0}), U2.57 (QSPI_SD0)
/QSPI_SD1: U1.2 (DO/IO_{1}), U2.59 (QSPI_SD1)
/QSPI_SD2: U1.3 (~WP/IO_{2}), U2.58 (QSPI_SD2)
/QSPI_SD3: U1.7 (~HOLD/~RESET/IO_{3}), U2.55 (QSPI_SD3)
/QSPI_SS: R3.2, U1.1 (~CS), U2.60 (QSPI_SS)
/SWCLK: U2.24 (SWCLK)
/SWD: U2.25 (SWD)
/VREG_AVDD: C3.1, R4.2, U2.46 (VREG_AVDD)
/VREG_LX: L1.2, U2.48 (VREG_LX)
/XIN: C10.1, U2.21 (XIN), Y1.1
/XOUT: C13.1, U2.22 (XOUT), Y1.3
B_0: A1.1 (OUT), U2.19 (GPIO15)
B_1: A2.1 (OUT), U2.27 (GPIO16)
B_2: A3.1 (OUT), U2.28 (GPIO17)
B_3: A4.1 (OUT), U2.29 (GPIO18)
B_4: A5.1 (OUT), U2.31 (GPIO19)
B_5: A6.1 (OUT), U2.32 (GPIO20)
B_6: A7.1 (OUT), U2.33 (GPIO21)
B_7: A8.1 (OUT), U2.34 (GPIO22)
B_8: A9.1 (OUT), U2.35 (GPIO23)
B_9: A10.1 (OUT), U2.40 (GPIO26_ADC0)
B_10: A11.1 (OUT), U2.41 (GPIO27_ADC1)
B_11: A12.1 (OUT), U2.42 (GPIO28_ADC2)
B_12: A13.1 (OUT), U2.43 (GPIO29_ADC3)
B_13: A14.1 (OUT), U2.4 (GPIO2)
B_14: A15.1 (OUT), U2.5 (GPIO3)
B_15: A16.1 (OUT), U2.9 (GPIO6)
B_16: A17.1 (OUT), U2.10 (GPIO7)
B_17: A18.1 (OUT), U2.12 (GPIO8)
B_18: A19.1 (OUT), U2.13 (GPIO9)
B_19: A20.1 (OUT), U2.14 (GPIO10)
B_20: A21.1 (OUT), U2.15 (GPIO11)
B_21: A22.1 (OUT), U2.16 (GPIO12)
B_22: A23.1 (OUT), U2.17 (GPIO13)
B_23: A24.1 (OUT), U2.18 (GPIO14)
DEBUG_LED: R2.1, U2.36 (GPIO24)
DEFAULT_LED: R1.1, U2.37 (GPIO25)
GND: A1.2 (GND), A2.2 (GND), A3.2 (GND), A4.2 (GND), A5.2 (GND), A6.2 (GND), A7.2 (GND), A8.2 (GND), A9.2 (GND), A10.2 (GND), A11.2 (GND), A12.2 (GND), A13.2 (GND), A14.2 (GND), A15.2 (GND), A16.2 (GND), A17.2 (GND), A18.2 (GND), A19.2 (GND), A20.2 (GND), A21.2 (GND), A22.2 (GND), A23.2 (GND), A24.2 (GND), C1.2, C2.2, C3.2, C4.2, C5.2, C6.2, C7.2, C8.2, C9.2, C10.2, C11.2, C12.2, C13.2, C14.2, C15.2, C16.2, C17.2, D1.1 (K), D2.1 (K), J2.3, J2.4, U1.4 (GND), U2.47 (VREG_PGND), U2.61 (GND), Y1.2, Y1.4
MCU_RUN: J3.3, U2.26 (RUN)
unnamed: D1.2 (A), R1.2
unnamed: D2.2 (A), R2.2
unnamed: R7.1, U2.51 (USB_DM)
unnamed: R6.1, U2.52 (USB_DP)
USB_BOOT: J1.4, R3.1
USB_D+: J1.2, R6.2
USB_D-: J1.1, R7.2
mainRX→rpTX: J3.1, U2.7 (GPIO4)
mainTX→rpRX: J3.2, U2.8 (GPIO5)

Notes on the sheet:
POWER
ABM8-272-T3
FLASH
CRYSTAL
MCU RP2350
DEBUG
FUNCTION
BALL_SENSOR
TSSP4038
抵抗はMCU近く
POWER_ON



Board: 2 copper layers, 150.0 x 150.0 mm, 56 parts (2 on the bottom side), 49 nets.

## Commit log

2026-06-28 Add .gitignore for KiCad project files
2026-06-28 Add README for RoboCup Junior 2026 PCB design files
    This README provides an overview of the PCB design files for RoboCup Junior 2026, including contents and software used.
